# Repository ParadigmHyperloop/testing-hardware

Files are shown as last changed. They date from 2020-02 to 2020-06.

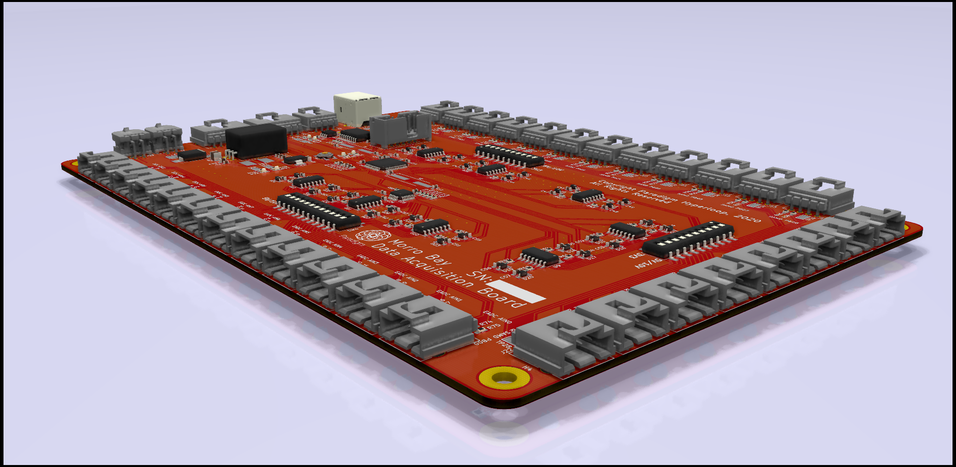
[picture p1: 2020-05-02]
morro-bay/PCB_Morro_Bay/Render1.png

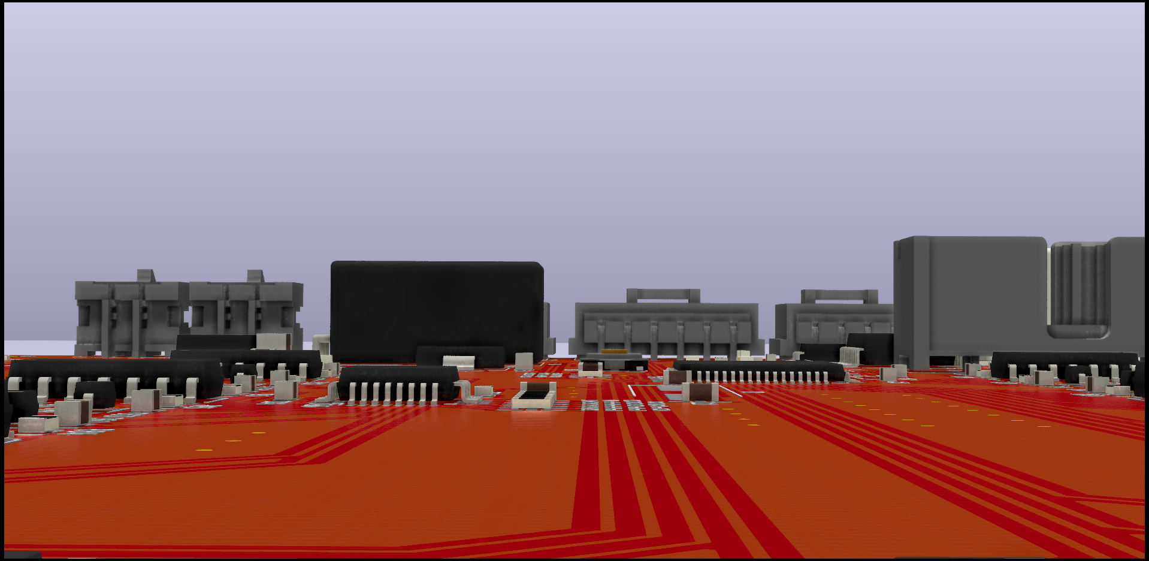
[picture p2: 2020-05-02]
morro-bay/PCB_Morro_Bay/Render4.png

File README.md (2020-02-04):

All schematics and layouts in KiCad, plus some simulations https://paradigmhyperloop.com

License See the LICENSE for full licensing details.

In summary, (you still need to read the whole thing), these boards are for Paradigm, and Paradigm only. It is shared with the world for the benefit of observers and potential Paradigm team members. If you wish to utilize these designs in any way, you must contact us first and receive written permission to utilize the designs for the purpose you require.

We don't want to be restrictive, and we will almost certainly grant you permission, but we want to know what you are using our designs for, and we want to make sure you are using them correctly and safely.

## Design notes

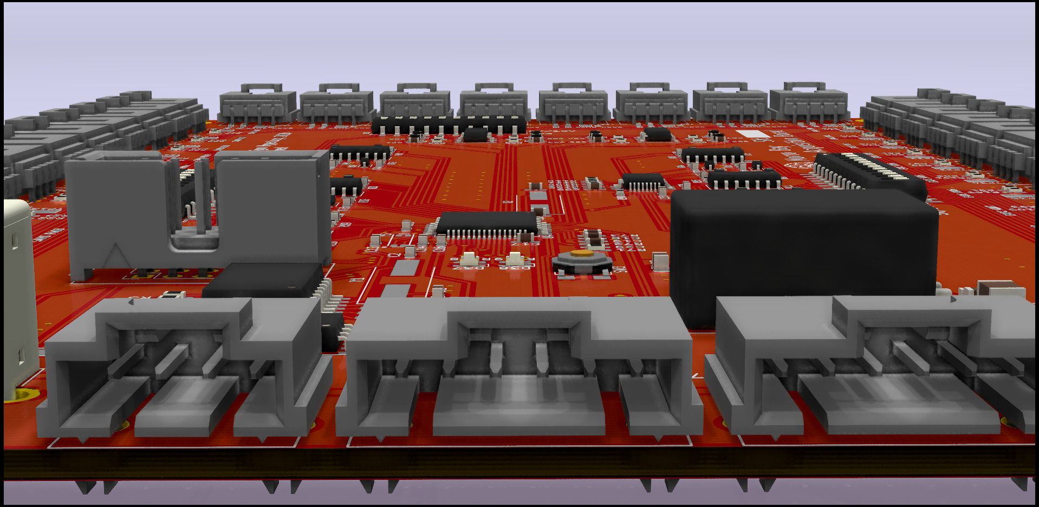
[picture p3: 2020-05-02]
morro-bay/PCB_Morro_Bay/Render2.png

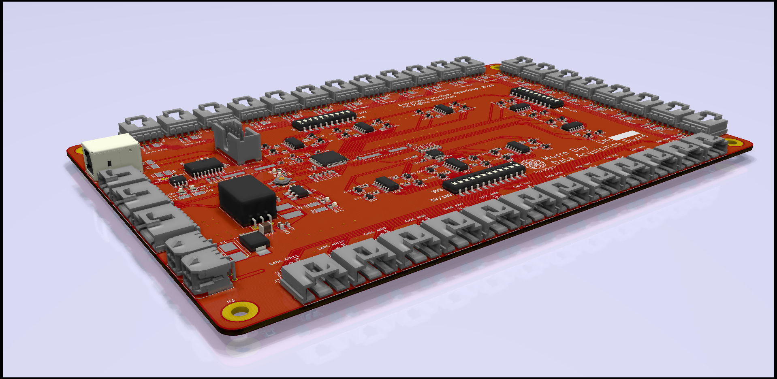
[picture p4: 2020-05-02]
morro-bay/PCB_Morro_Bay/Render3.png

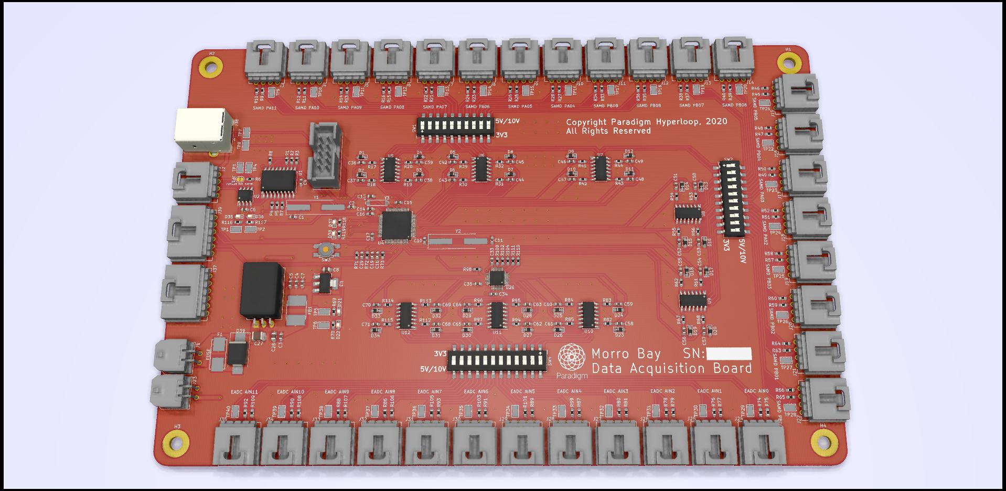
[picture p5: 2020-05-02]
morro-bay/PCB_Morro_Bay/Render5.png

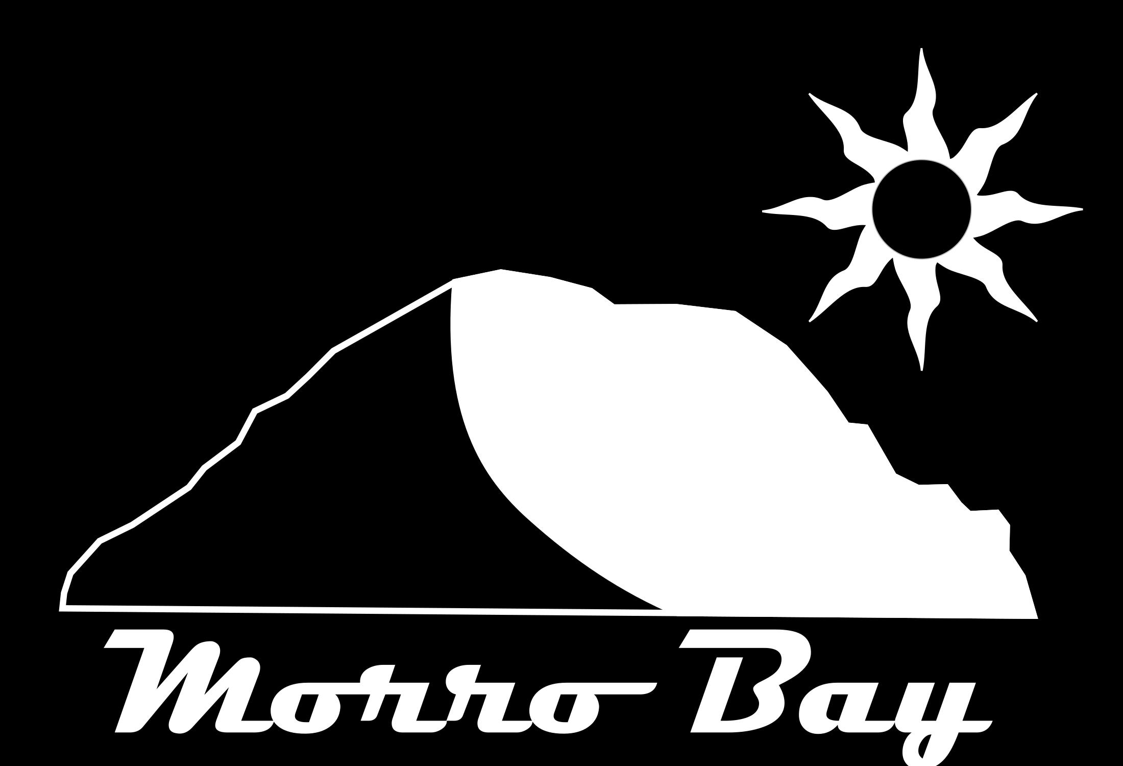
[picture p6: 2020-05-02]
morro-bay/PCB_Morro_Bay/MorroBay.png

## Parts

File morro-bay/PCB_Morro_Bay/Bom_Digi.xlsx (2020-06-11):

Manufacturer Part Number | Manufacturer | Digi-Key Part Number | Reference Designator | Quantity | Unit Price | Extended Price
CL10A106MA8NRNC | Samsung Electro-Mechanics | 1276-1869-1-ND | C5, C7, C12, C21 | 4 | $0.54 | $2.16
CC0603KRX7R8BB104 | Yageo | 311-1341-1-ND | C3, C4, C6, C9, C15-C18, C20, C22-C26, C29-C31, C34-C39, C42-C65, C67-C71 | 52 | $0.08 | $4.16
CL10C180FB8NNNC | Samsung Electro-Mechanics | 1276-2206-1-ND | C1, C2, C10, C11 | 4 | $0.30 | $1.20
CL10C090CB8NNNC | Samsung Electro-Mechanics | 1276-2142-1-ND | C13, C14 | 2 | $0.15 | $0.30
CL10B105KA8NNNC | Samsung Electro-Mechanics | 1276-1184-1-ND | C19 | 1 | $0.15 | $0.15
GRM32EC72A106KE05L | Murata Electronics | 490-16266-1-ND | C27 | 1 | $2.28 | $2.28
CL21A226MAQNNNE | Samsung Electro-Mechanics | 1276-2908-1-ND | C8, C28, C32, C40, C41, C66 | 6 | $0.80 | $4.80
C0603C331J5GACTU | KEMET | 399-1068-1-ND | C33 | 1 | $0.15 | $0.15
MM3Z3V3ST1G | ON Semiconductor | MM3Z3V3ST1GOSCT-ND | D1-D20, D23-D34 | 32 | $0.18 | $5.84
150060VS75000 | Würth Elektronik | 732-4980-1-ND | D21, D22 | 2 | $0.21 | $0.42
LTST-C191KFKT | Lite-On Inc. | 160-1445-1-ND | D35, D36 | 2 | $0.36 | $0.72
150060SS75000 | Würth Elektronik | 732-4979-1-ND | D37 | 1 | $0.21 | $0.21
150060YS75000 | Würth Elektronik | 732-4981-1-ND | D38 | 1 | $0.21 | $0.21
STPS5L60S | STMicroelectronics | 497-8487-1-ND | D39 | 1 | $1.22 | $1.22
0154003.DR | Littelfuse Inc. | F1226CT-ND | F1 | 1 | $3.85 | $3.85
HI2220P701R-10 | Laird-Signal Integrity Products | 240-2428-1-ND | FB1 | 1 | $1.27 | $1.27
FBMH3216HM221NTV | Taiyo Yuden | 587-3834-1-ND | FB2 | 1 | $0.63 | $0.63
0705510038 | Molex | WM14059-ND | J2-J22, J24-J35 | 33 | $2.40 | $79.33
0430450400 | Molex | WM1814-ND | J1, J23 | 2 | $2.01 | $4.02
5103308-1 | TE Connectivity AMP Connectors | A33159-ND | J36 | 1 | $1.98 | $1.98
0705510005 | Molex | WM14056-ND | J37, J39 | 2 | $2.13 | $4.26
UJ2-BH-1-TH | CUI Devices | 102-3999-ND | J38 | 1 | $0.81 | $0.81
RMCF0603FT10K0 | Stackpole Electronics Inc | RMCF0603FT10K0CT-ND | R1-R5, R7, R8, R72 | 8 | $0.16 | $1.28
RMCF0603JT120R | Stackpole Electronics Inc | RMCF0603JT120RCT-ND | R6 | 1 | $0.16 | $0.16
ERJ-PB3B5112V | Panasonic Electronic Components | P20167CT-ND | R9, R11, R13, R15, R21, R23, R25, R27, R33, R35, R37, R39, R45, R47, R74, R76, R78, R80, R99, R101, R103, R105 | 22 | $0.34 | $7.45
ERJ-PB3B1003V | Panasonic Electronic Components | P20200CT-ND | R10, R12, R14, R16, R22, R24, R26, R28, R34, R36, R38, R40, R46, R48, R50, R52, R58, R60, R64, R66, R75, R77, R79, R81, R87, R89, R91, R93, R106-R109 | 32 | $0.25 | $7.88
ERA-3AEB2053V | Panasonic Electronic Components | P205KDBCT-ND | R49, R51, R57, R59, R63, R65, R86, R88, R90, R92 | 10 | $0.46 | $4.60
RMCF0603FT620R | Stackpole Electronics Inc | RMCF0603FT620RCT-ND | R69 | 1 | $0.16 | $0.16
ESR03EZPJ331 | Rohm Semiconductor | RHM330DCT-ND | R70, R71, R118, R119 | 4 | $0.16 | $0.64
RMCF0603JJ1K00 | Stackpole Electronics Inc | RMCF0603JJ1K00CT-ND | R73 | 1 | $0.16 | $0.16
RMCF0603FT47R0 | Stackpole Electronics Inc | RMCF0603FT47R0CT-ND | R98, R100, R102, R104, R110, R111 | 6 | $0.16 | $0.96
RMCF0603FT470R | Stackpole Electronics Inc | RMCF0603FT470RCT-ND | R17-R20, R29-R32, R41-R44, R53-R56, R61, R62, R67, R68, R82-R85, R94-R97, R112-R117 | 34 | $0.03 | $0.88
DS04-254-2-10BK-SMT | CUI Devices | 2223-DS04-254-2-10BK-SMT-ND | SW1, SW2 | 2 | $1.72 | $3.44
TL3305AF160QG | E-Switch | EG5350CT-ND | SW3 | 1 | $0.32 | $0.32
DS04-254-2-12BK-SMT | CUI Devices | 2223-DS04-254-2-12BK-SMT-ND | SW4 | 1 | $1.83 | $1.83
5015 | Keystone Electronics | 36-5015CT-ND | TP1-TP40 | 40 | $0.58 | $23.05
MCP2515T-I/SO | Microchip Technology | MCP2515T-I/SOCT-ND | U1 | 1 | $2.92 | $2.92
SN65HVD232DR | Texas Instruments | 296-26344-1-ND | U2 | 1 | $3.13 | $3.13
AZ1117IH-3.3TRG1 | Diodes Incorporated | AZ1117IH-3.3TRG1DICT-ND | U3 | 1 | $0.58 | $0.58
ATSAMD21J18A-AUT | Microchip Technology | ATSAMD21J18A-AUTCT-ND | U4 | 1 | $5.29 | $5.29
LM2902LVIDR | Texas Instruments | 296-51255-1-ND | U5-U12 | 8 | $0.77 | $6.16
V7805-2000R | CUI Inc. | 102-2188-ND | U13 | 1 | $14.71 | $14.71
ADS114S08BIPBSR | Texas Instruments | 296-50714-1-ND | U26 | 1 | $13.29 | $13.29
ABLS2-8.000MHZ-D4Y-T | Abracon LLC | 535-9864-1-ND | Y1 | 1 | $0.74 | $0.74
ABLS2-30.000MHZ-D4YF-T | Abracon LLC | 535-9887-1-ND | Y2 | 1 | $0.69 | $0.69
MC-146 32.7680KA-AC0: ROHS | EPSON | SER4303CT-ND | Y3 | 1 | $0.64 | $0.64
 |  |  |  |  |  | $220.93

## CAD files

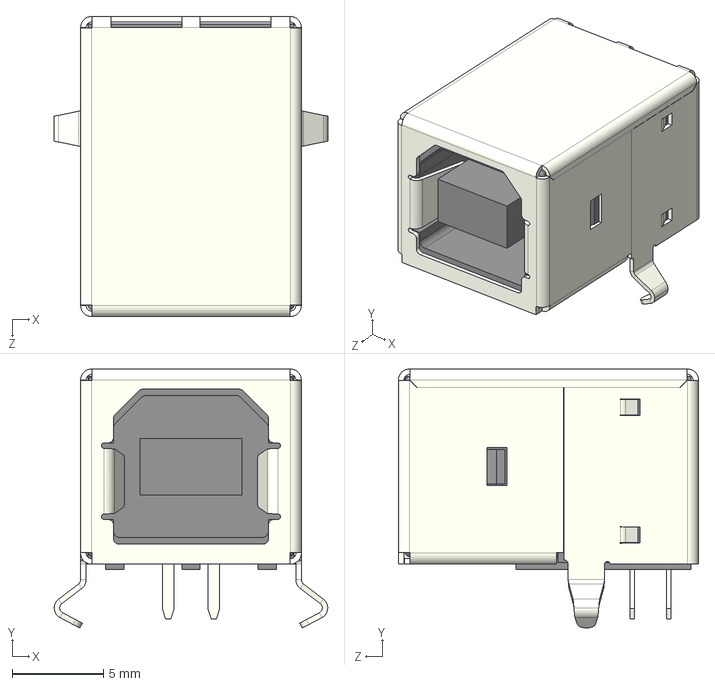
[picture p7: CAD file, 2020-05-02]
morro-bay/Models/CUI_DEVICES_UJ2-BH-1-TH.step
15.0 x 14.2 x 16.5 mm

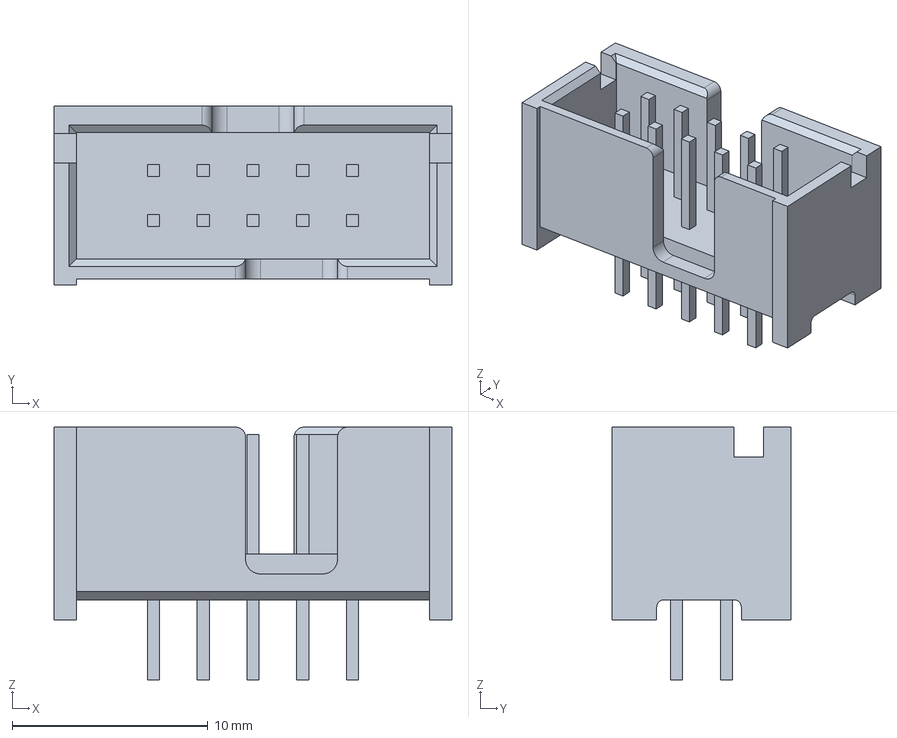
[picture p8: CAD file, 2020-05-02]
morro-bay/Models/c-5103308-1-b-3d.stp
20.3 x 9.14 x 12.9 mm

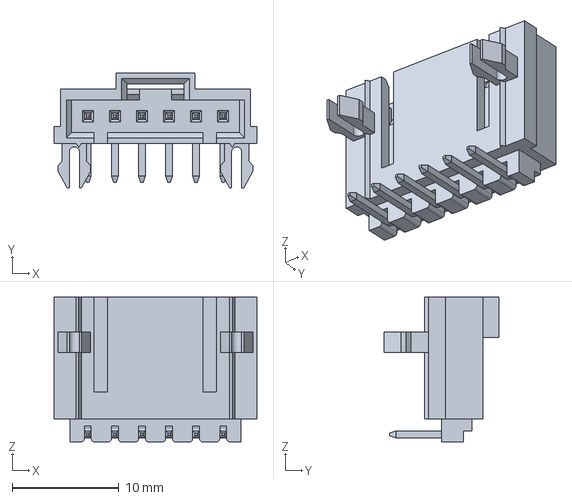
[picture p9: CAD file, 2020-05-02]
morro-bay/Models/705510005.stp
19.0 x 10.8 x 13.6 mm

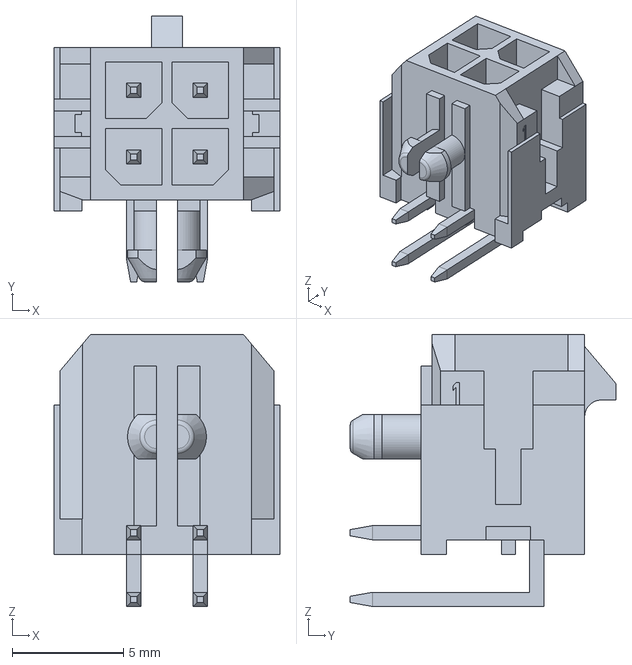
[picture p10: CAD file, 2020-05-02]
morro-bay/Models/430450400.stp
10.2 x 11.9 x 12.2 mm

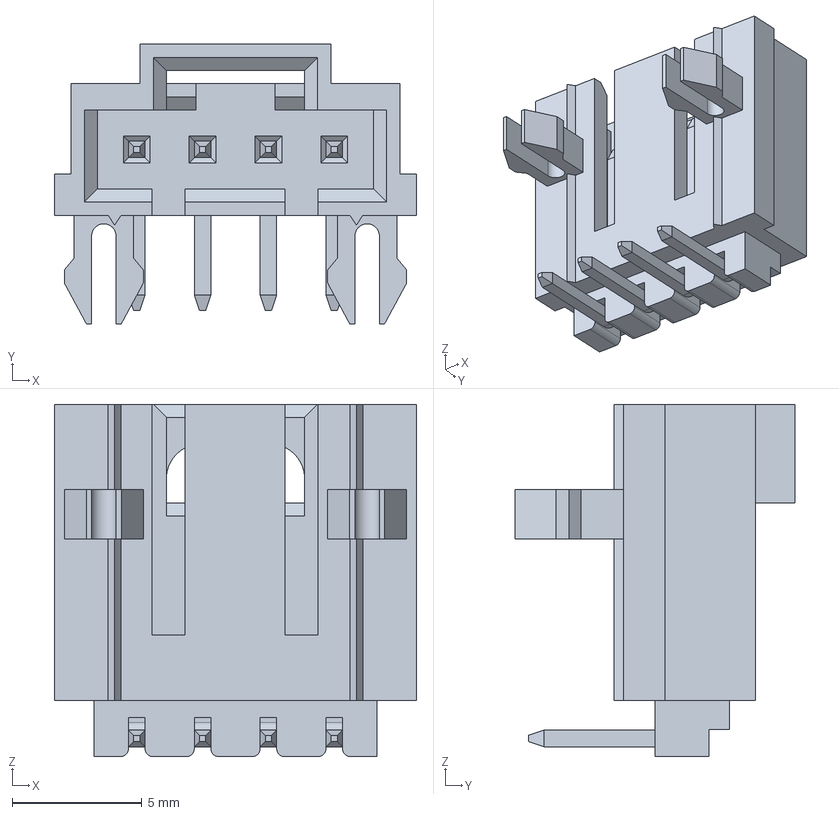
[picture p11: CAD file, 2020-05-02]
morro-bay/Models/705510038.stp
14.0 x 10.8 x 13.6 mm

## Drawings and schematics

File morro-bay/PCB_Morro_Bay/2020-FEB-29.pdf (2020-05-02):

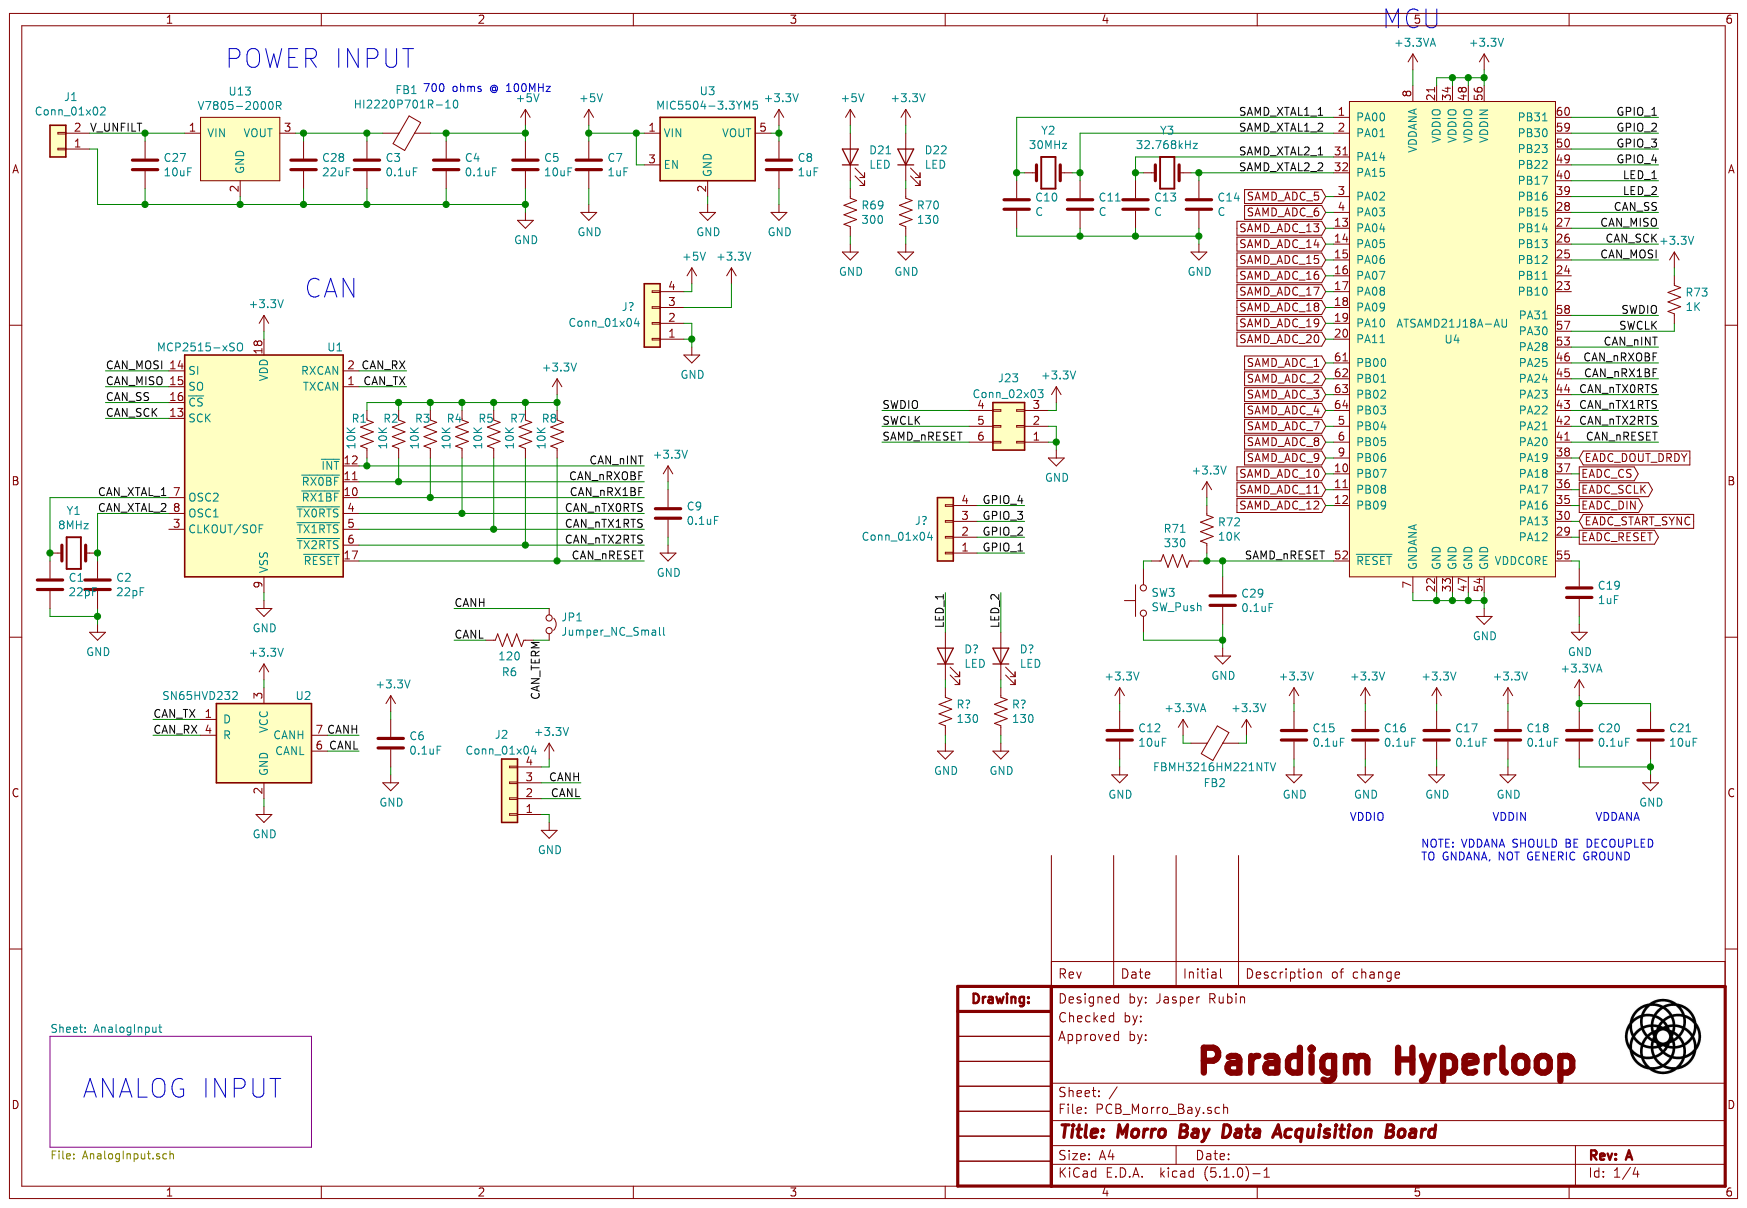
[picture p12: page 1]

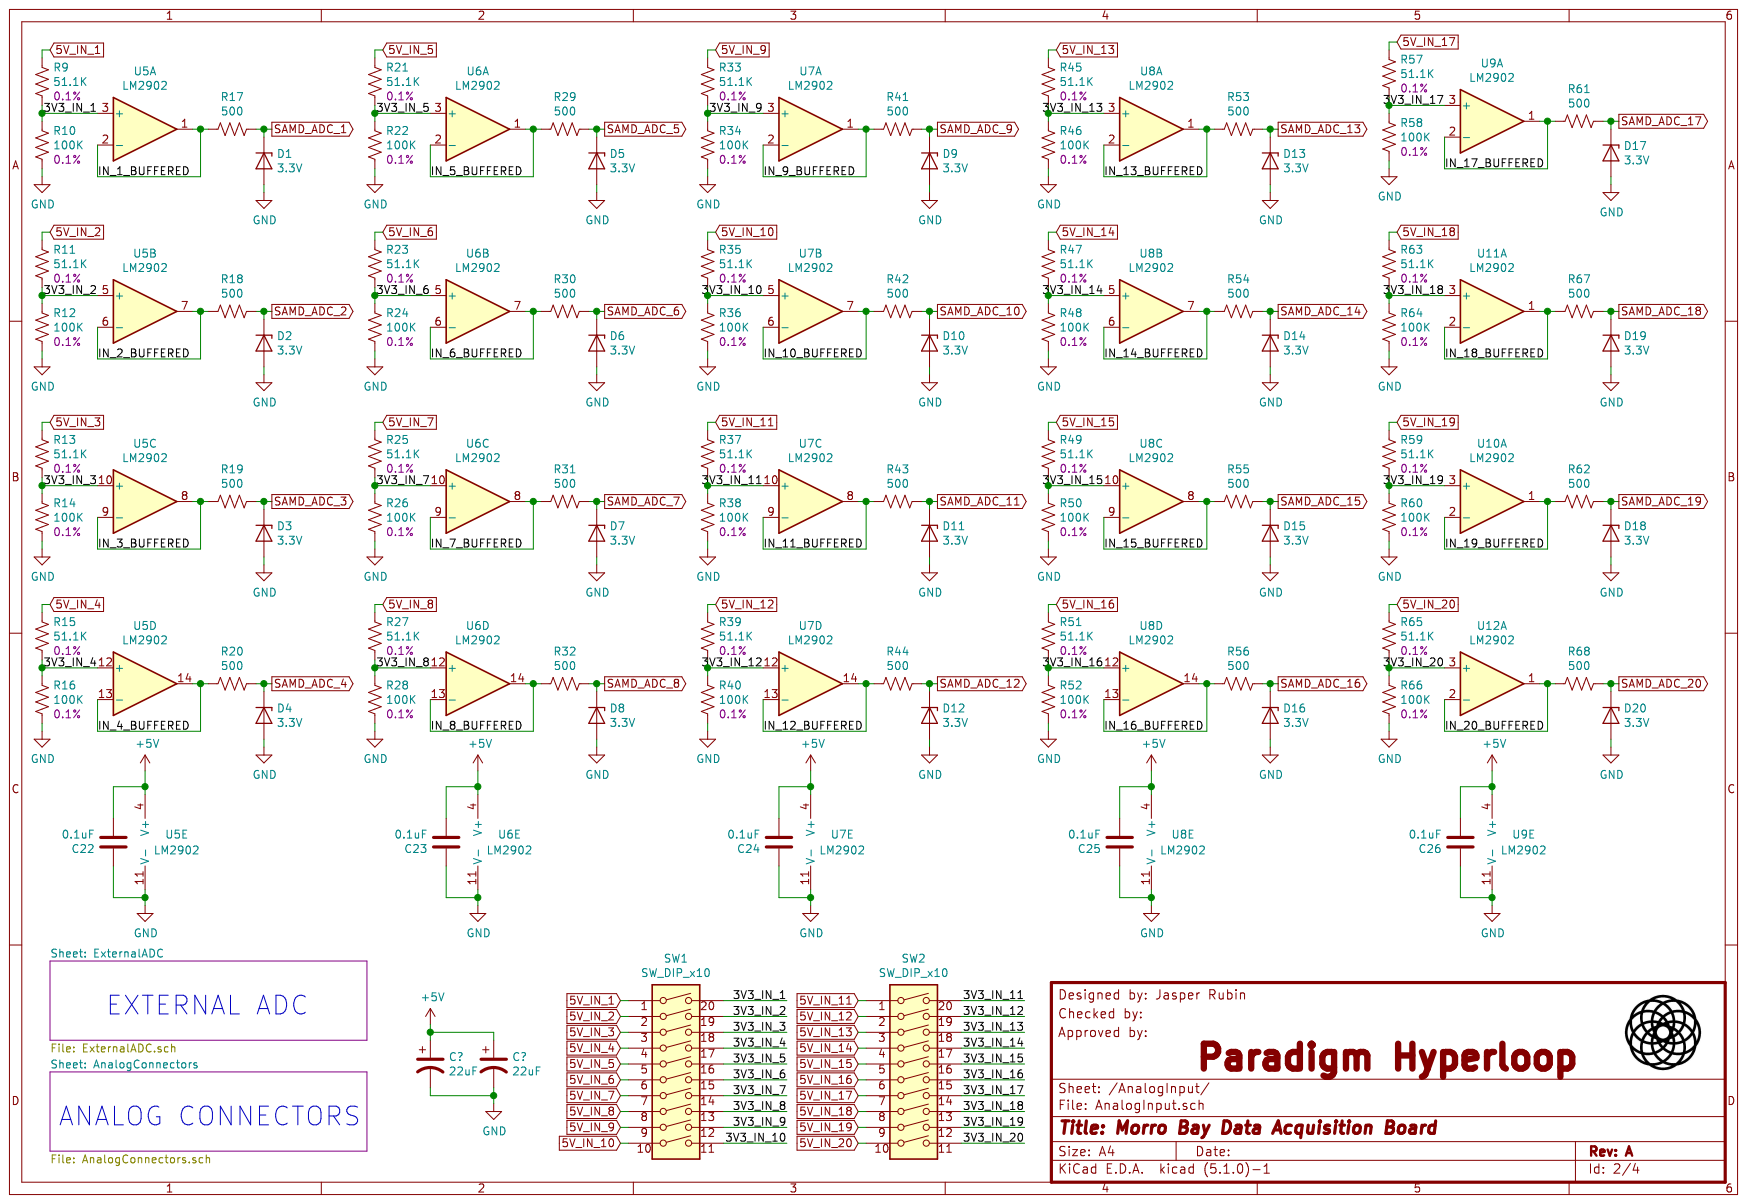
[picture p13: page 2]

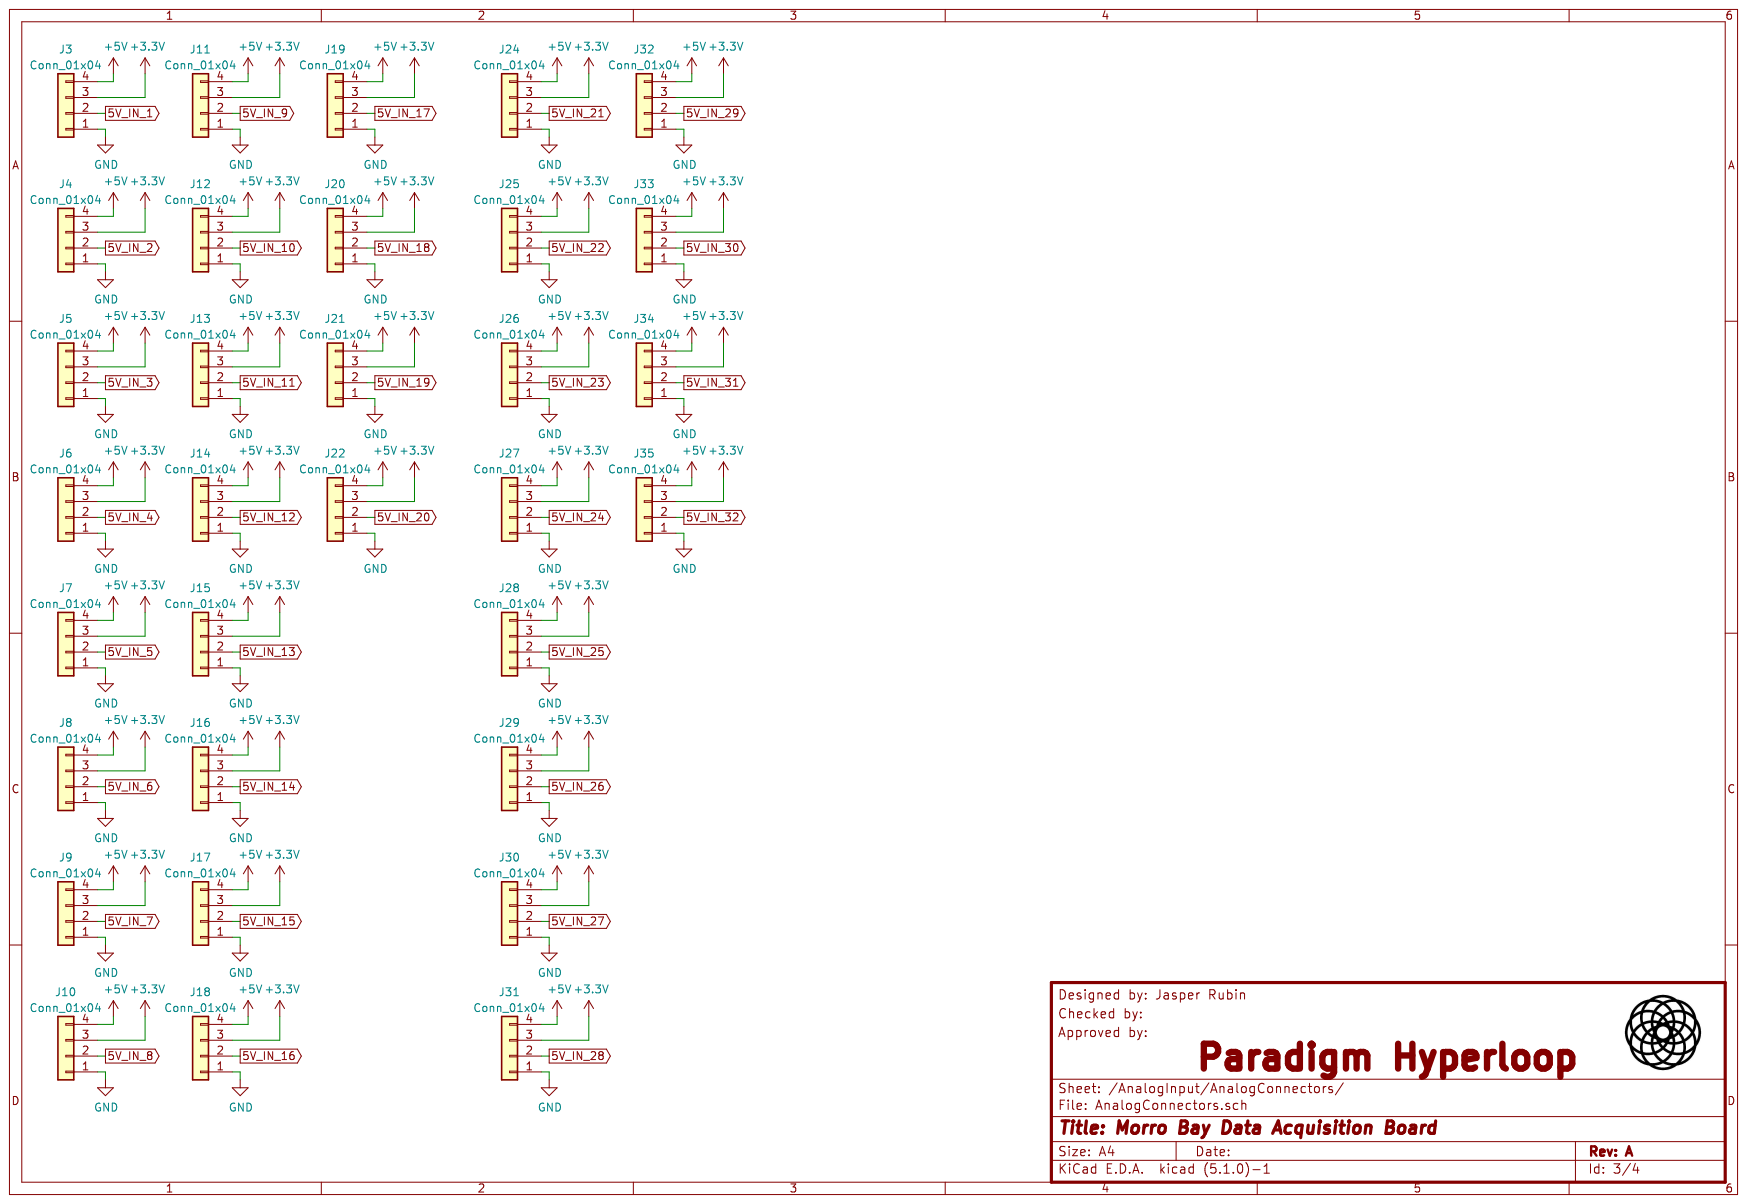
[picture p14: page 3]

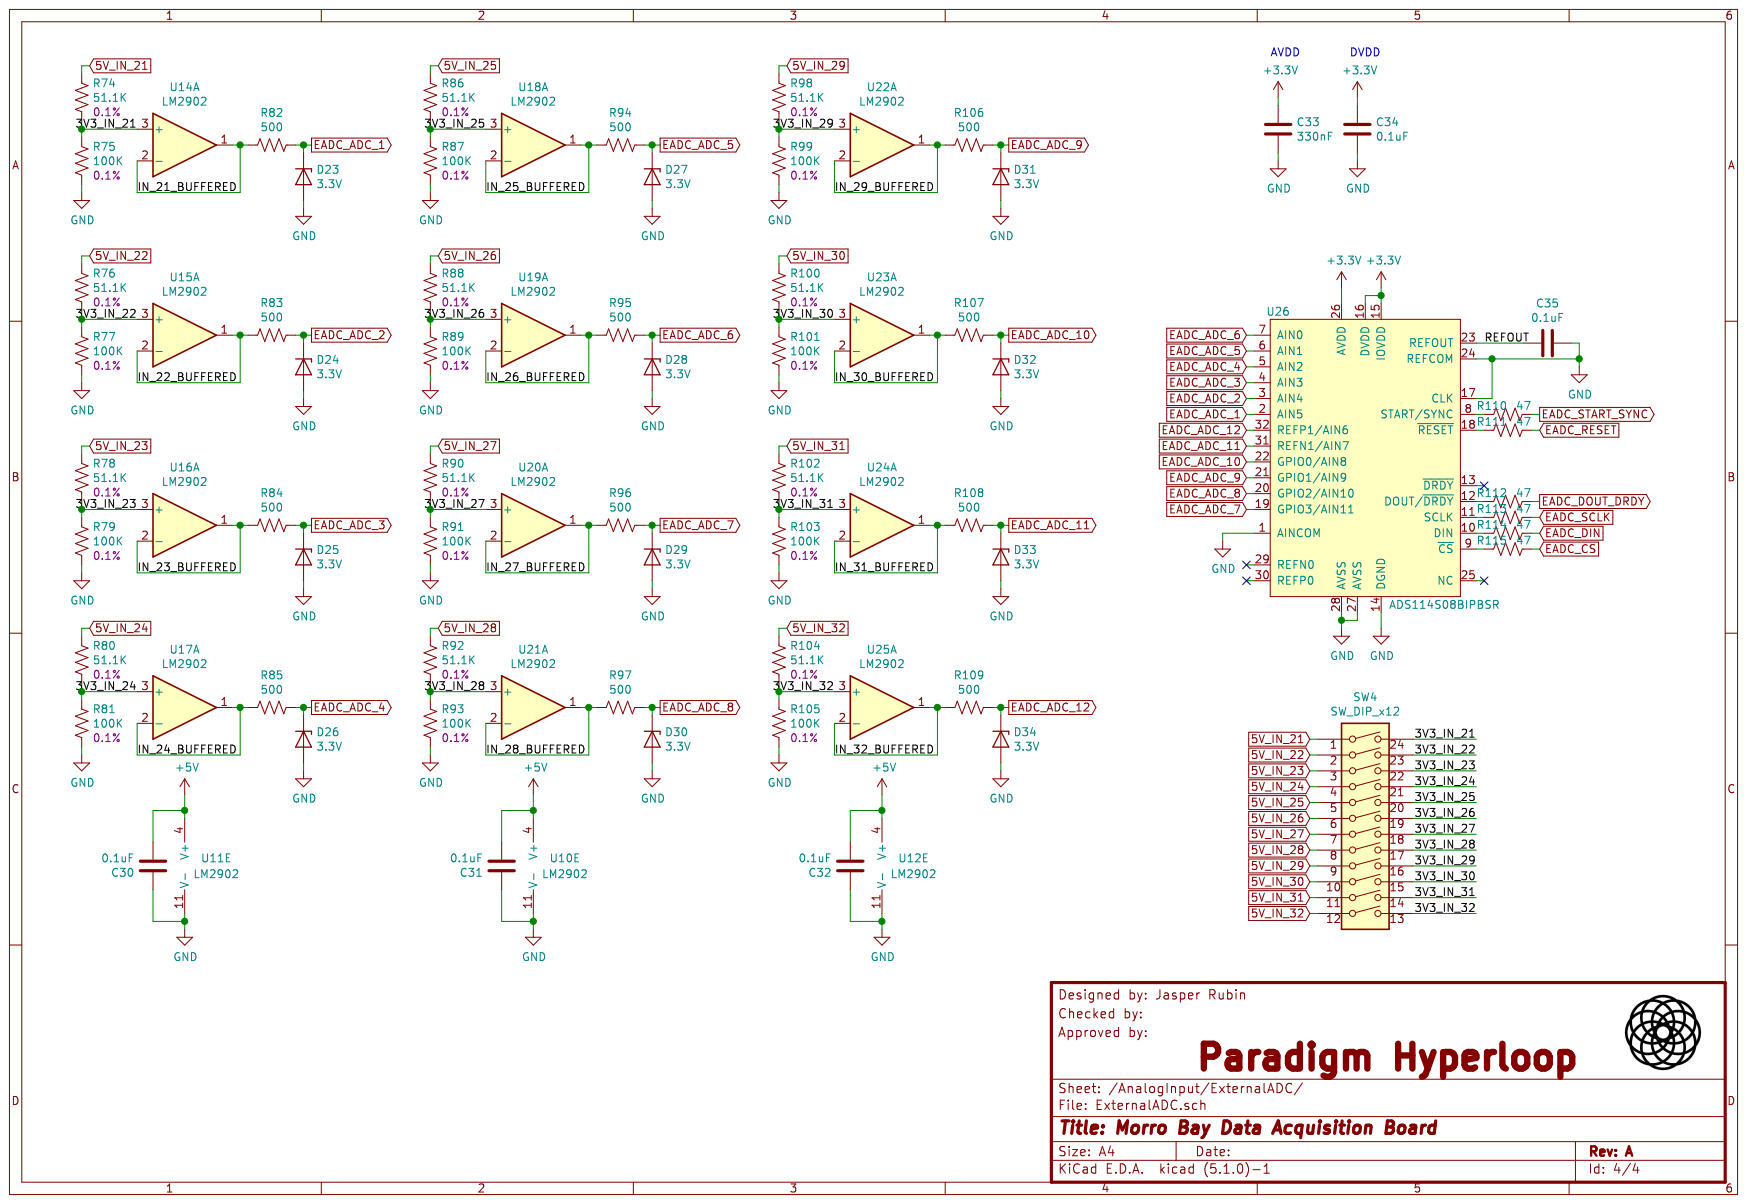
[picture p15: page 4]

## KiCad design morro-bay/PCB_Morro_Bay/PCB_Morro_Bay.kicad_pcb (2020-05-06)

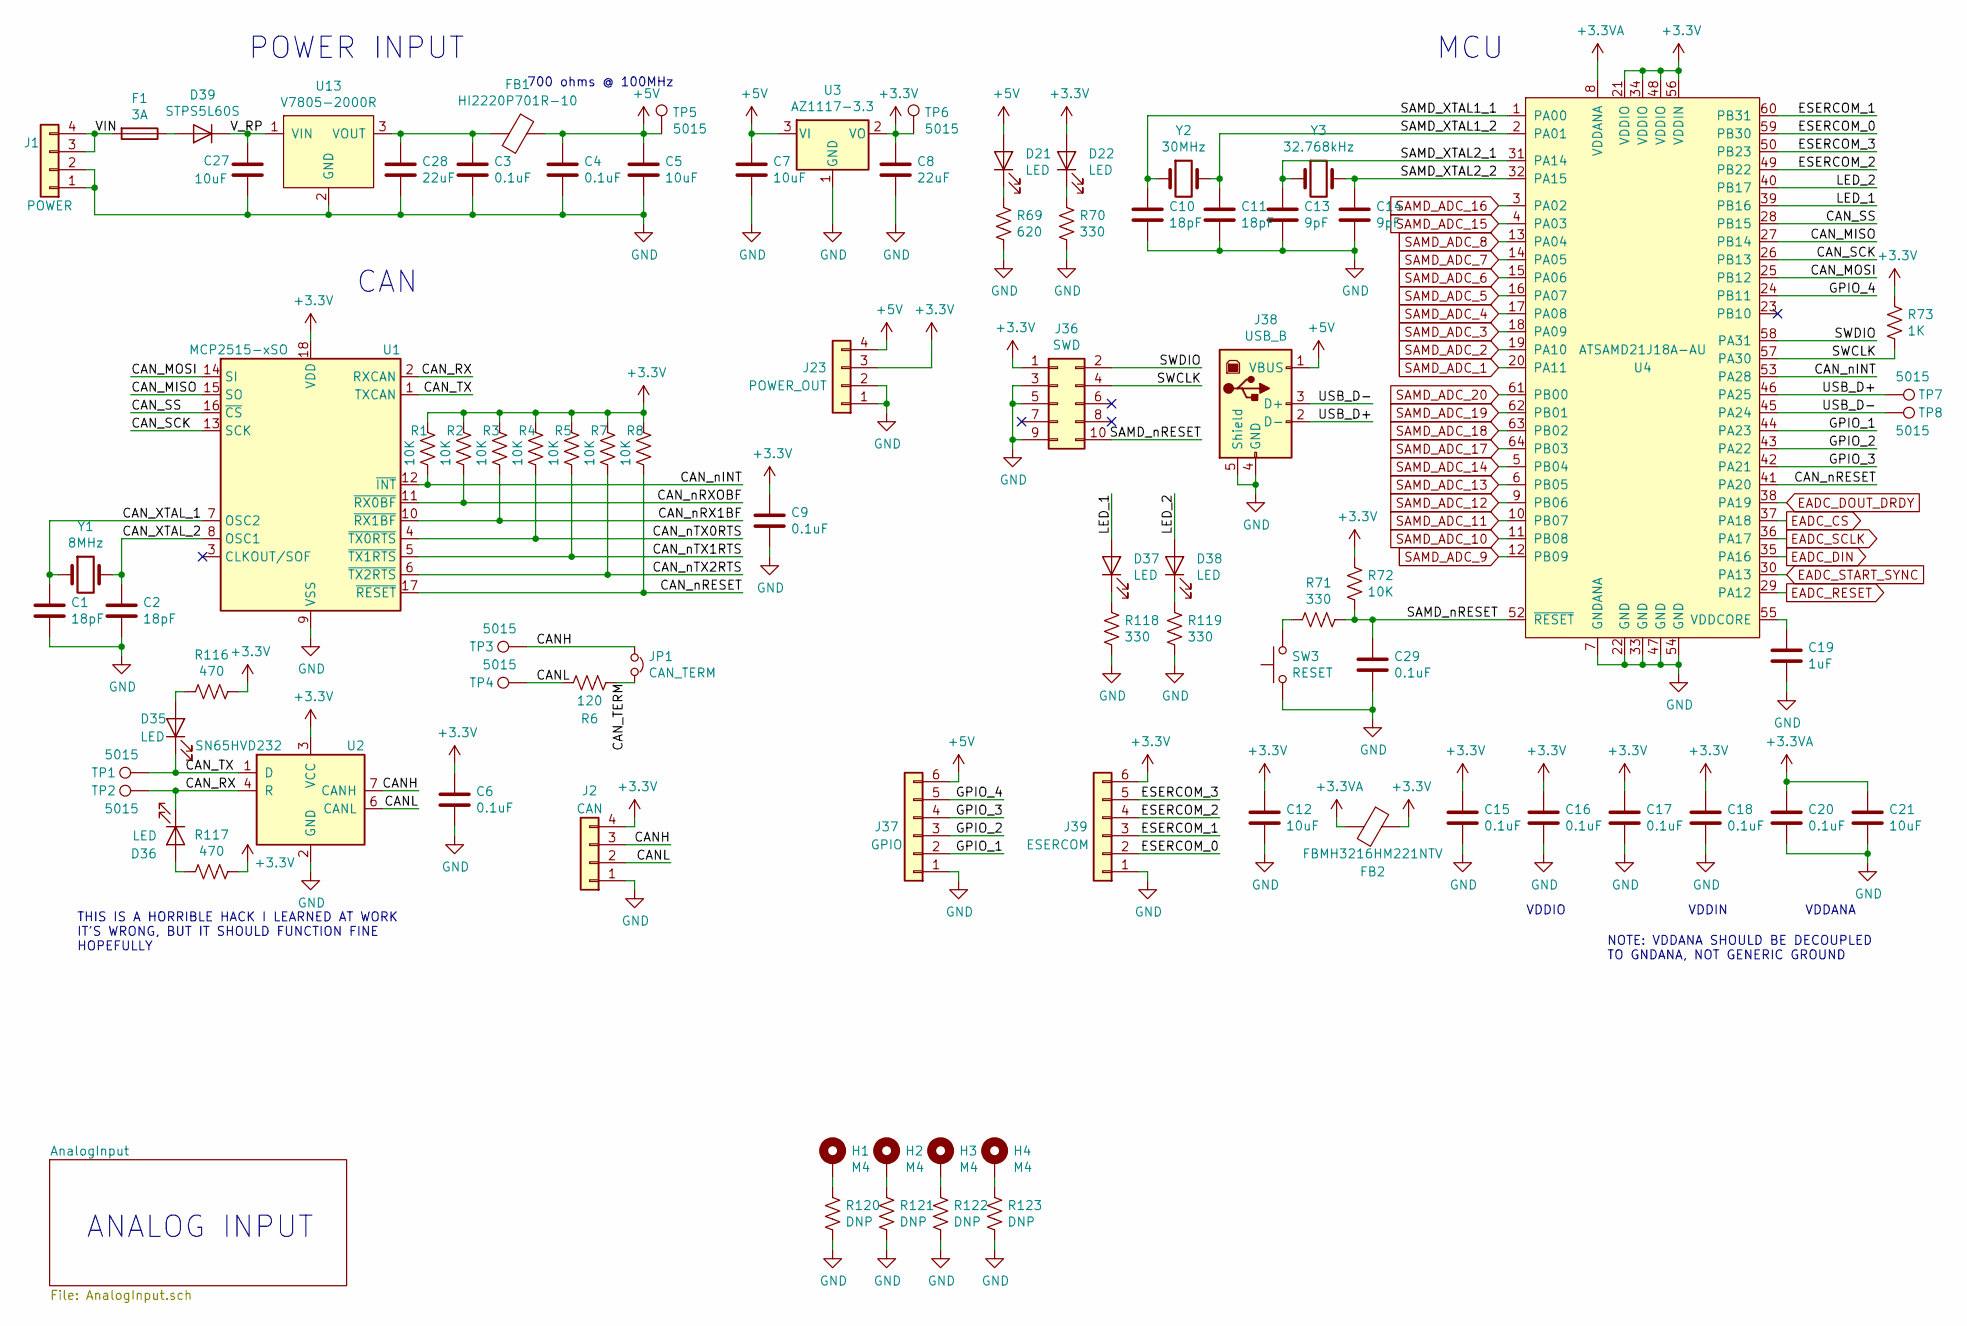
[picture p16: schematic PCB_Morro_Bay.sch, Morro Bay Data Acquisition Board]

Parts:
C1, C2, C10, C11: 18pF; C_0603_1608Metric_Pad1.05x0.95mm_HandSolder; Part Number CL10C180FB8NNNC
C3, C4, C6, C9, C15, C16, C17, C18, C20, C29: 0.1uF; C_0603_1608Metric_Pad1.05x0.95mm_HandSolder; Part Number CC0603KRX7R8BB104
C5, C7, C12, C21: 10uF; C_0603_1608Metric_Pad1.05x0.95mm_HandSolder; Part Number CL10A106MA8NRNC
C8, C28: 22uF; C_0805_2012Metric_Pad1.15x1.40mm_HandSolder; Part Number CL21A226MAQNNNE
C13, C14: 9pF; C_0603_1608Metric_Pad1.05x0.95mm_HandSolder; Part Number CL10C090CB8NNNC
C19: 1uF; C_0603_1608Metric_Pad1.05x0.95mm_HandSolder; Part Number CL10B105KA8NNNC
C27: 10uF; C_1210_3225Metric_Pad1.42x2.65mm_HandSolder; Part Number GRM32EC72A106KE05L
D21, D22: LED; LED_0603_1608Metric_Castellated; Part Number 150060VS75000
D35, D36: LED; LED_0603_1608Metric_Castellated; Part Number LTST-C191KFKT
D37: LED; LED_0603_1608Metric_Castellated; Part Number 150060SS75000
D38: LED; LED_0603_1608Metric_Castellated; Part Number 150060YS75000
D39: STPS5L60S; D_SMC_Handsoldering; Part Number STPS5L60S
F1: 3A; Fuse_Littelfuse_0154003.DR; Part Number 0154003.DR
FB1: HI2220P701R-10; Ferrite_Laird_HI2220P701R-10; Part Number HI2220P701R-10
FB2: FBMH3216HM221NTV; L_1206_3216Metric_Pad1.42x1.75mm_HandSolder; Part Number FBMH3216HM221NTV
H1, H2, H3, H4: M4; MountingHole_4.3mm_M4_Pad
J1: POWER; Molex_Micro-Fit_3.0_43045-0400_2x02_P3.00mm_Horizontal; Part Number 0430450400
J2: CAN; Connector_Molex_SL_4POS_0705510038; Part Number 0705510038
J23: POWER_OUT; Molex_Micro-Fit_3.0_43045-0400_2x02_P3.00mm_Horizontal; Part Number 0430450400
J36: SWD; Connector_TE_5103308-1; Part Number 5103308-1
J37: GPIO; Connector_Molex_SL_6POS_0705510005; Part Number 0705510005
J38: USB_B; USB_B_OST_USB-B1HSxx_Horizontal; Part Number UJ2-BH-1-TH
J39: ESERCOM; Connector_Molex_SL_6POS_0705510005; Part Number 0705510005
JP1: CAN_TERM; SolderJumper-2_P1.3mm_Open_RoundedPad1.0x1.5mm
R1, R2, R3, R4, R5, R7, R8, R72: 10K; R_0603_1608Metric_Pad1.05x0.95mm_HandSolder; Part Number RMCF0603FT10K0
R6: 120; R_0603_1608Metric_Pad1.05x0.95mm_HandSolder; Part Number RMCF0603JT120R
R69: 620; R_0603_1608Metric_Pad1.05x0.95mm_HandSolder; Part Number RMCF0603FT620R
R70, R71, R118, R119: 330; R_0603_1608Metric_Pad1.05x0.95mm_HandSolder; Part Number ESR03EZPJ331
R73: 1K; R_0603_1608Metric_Pad1.05x0.95mm_HandSolder; Part Number RMCF0603JJ1K00
R116, R117: 470; R_0603_1608Metric_Pad1.05x0.95mm_HandSolder; Part Number RMCF0603FT470R
R120, R121, R122, R123: DNP; R_0805_2012Metric_Pad1.15x1.40mm_HandSolder
SW3: RESET; SW_SPST_TL3305A; Part Number TL3305AF160QG
TP1, TP2, TP3, TP4, TP5, TP6, TP7, TP8: 5015; TestPoint_Keystone_5015_Micro-Minature; Part Number 5015
U1: MCP2515-xSO; SOIC-18W_7.5x11.6mm_P1.27mm; Part Number MCP2515T-I/SO
U2: SN65HVD232; SOIC-8_3.9x4.9mm_P1.27mm; Part Number SN65HVD232DR
U3: AZ1117-3.3; SOT-223-3_TabPin2; Part Number AZ1117IH-3.3TRG1
U4: ATSAMD21J18A-AU; TQFP-64_10x10mm_P0.5mm; Part Number ATSAMD21J18A-AUT
U13: V7805-2000R; Converter_DCDC_RECOM_R-78HB-0.5L_THT; Part Number V7805-2000R
Y1: 8MHz; Crystal_SMD_HC49-SD_HandSoldering; Part Number ABLS2-8.000MHZ-D4Y-T
Y2: 30MHz; Crystal_SMD_HC49-SD_HandSoldering; Part Number ABLS2-30.000MHZ-D4YF-T
Y3: 32.768kHz; Crystal_Epson_MC-146; Part Number MC-146 32.7680KA-AC0: ROHS

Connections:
+3.3VA: C20.1, C21.1, FB2.2, U4.8 (VDDANA)
+3V3: C6.1, C8.1, C9.1, C12.1, C15.1, C16.1, C17.1, C18.1, D22.2 (A), FB2.1, J2.4, J23.3, J36.1, J39.6, R1.1, R2.1, R3.1, R4.1, R5.1, R7.1, R8.1, R72.1, R73.1, R116.1, R117.1, TP6.1, U1.18 (VDD), U2.3 (VCC), U3.2 (VO), U4.21 (VDDIO), U4.34 (VDDIO), U4.48 (VDDIO), U4.56 (VDDIN); also elsewhere on the board
+5V: C4.1, C5.1, C7.1, D21.2 (A), FB1.1, J23.4, J37.6, J38.1 (VBUS), TP5.1, U3.3 (VI); also elsewhere on the board
/CANH: J2.3, JP1.1, TP3.1, U2.7 (CANH)
/CANL: J2.2, R6.2, TP4.1, U2.6 (CANL)
/CAN_MISO: U1.15 (SO), U4.27 (PB14)
/CAN_MOSI: U1.14 (SI), U4.25 (PB12)
/CAN_RX: D36.1 (K), TP2.1, U1.2 (RXCAN), U2.4 (R)
/CAN_SCK: U1.13 (SCK), U4.26 (PB13)
/CAN_SS: U1.16 (~CS), U4.28 (PB15)
/CAN_TERM: JP1.2, R6.1
/CAN_TX: D35.1 (K), TP1.1, U1.1 (TXCAN), U2.1 (D)
/CAN_XTAL_1: C1.1, U1.7 (OSC2), Y1.1
/CAN_XTAL_2: C2.1, U1.8 (OSC1), Y1.2
/CAN_nINT: R1.2, U1.12 (~INT), U4.53 (PA28)
/CAN_nRESET: R8.2, U1.17 (~RESET), U4.41 (PA20)
/CAN_nRX1BF: R3.2, U1.10 (~RX1BF)
/CAN_nRXOBF: R2.2, U1.11 (~RX0BF)
/CAN_nTX0RTS: R4.2, U1.4 (~TX0RTS)
/CAN_nTX1RTS: R5.2, U1.5 (~TX1RTS)
/CAN_nTX2RTS: R7.2, U1.6 (~TX2RTS)
/ESERCOM_0: J39.2, U4.59 (PB30)
/ESERCOM_1: J39.3, U4.60 (PB31)
/ESERCOM_2: J39.4, U4.49 (PB22)
/ESERCOM_3: J39.5, U4.50 (PB23)
/GPIO_1: J37.2, U4.44 (PA23)
/GPIO_2: J37.3, U4.43 (PA22)
/GPIO_3: J37.4, U4.42 (PA21)
/GPIO_4: J37.5, U4.24 (PB11)
/LED_1: D37.2 (A), U4.39 (PB16)
/LED_2: D38.2 (A), U4.40 (PB17)
/SAMD_XTAL1_1: C10.1, U4.1 (PA00), Y2.1
/SAMD_XTAL1_2: C11.1, U4.2 (PA01), Y2.2
/SAMD_XTAL2_1: C13.1, U4.31 (PA14), Y3.1
/SAMD_XTAL2_2: C14.1, U4.32 (PA15), Y3.2
/SAMD_nRESET: C29.1, J36.10, R71.1, R72.2, U4.52 (~RESET~)
/SWCLK: J36.4, R73.2, U4.57 (PA30)
/SWDIO: J36.2, U4.58 (PA31)
/USB_D+: J38.2 (D-), TP7.1, U4.46 (PA25)
/USB_D-: J38.3 (D+), TP8.1, U4.45 (PA24)
/VIN: F1.2, J1.3, J1.4
/V_RP: C27.1, D39.1 (K), U13.1 (VIN)
EADC_CS: U4.37 (PA18); also elsewhere on the board
EADC_DIN: U4.35 (PA16); also elsewhere on the board
EADC_DOUT_DRDY: U4.38 (PA19); also elsewhere on the board
EADC_RESET: U4.29 (PA12); also elsewhere on the board
EADC_SCLK: U4.36 (PA17); also elsewhere on the board
EADC_START_SYNC: U4.30 (PA13); also elsewhere on the board
GND: C1.2, C2.2, C3.2, C4.2, C5.2, C6.2, C7.2, C8.2, C9.2, C10.2, C11.2, C12.2, C13.2, C14.2, C15.2, C16.2, C17.2, C18.2, C19.2, C20.2, C21.2, C27.2, C28.2, C29.2, J1.1, J1.2, J2.1, J23.1, J23.2, J36.3, J36.5, J36.9, J37.1, J38.4 (GND), J38.5 (Shield), J39.1, R69.2, R70.2, R118.2, R119.2, R120.2, R121.2, R122.2, R123.2, SW3.1, U1.9 (VSS), U2.2 (GND), U3.1 (GND), U4.7 (GNDANA), U4.22 (GND), U4.33 (GND), U4.47 (GND), U4.54 (GND), U13.2 (GND); also elsewhere on the board
unnamed: C19.1, U4.55 (VDDCORE)
unnamed: C3.1, C28.1, FB1.2, U13.3 (VOUT)
unnamed: D21.1 (K), R69.1
unnamed: D22.1 (K), R70.1
unnamed: D35.2 (A), R116.2
unnamed: D36.2 (A), R117.2
unnamed: D37.1 (K), R118.1
unnamed: D38.1 (K), R119.1
unnamed: D39.2 (A), F1.1
unnamed: H1.1, R120.1
unnamed: H2.1, R121.1
unnamed: H3.1, R122.1
unnamed: H4.1, R123.1
unnamed: R71.2, SW3.2
SAMD_ADC_1: U4.20 (PA11); also elsewhere on the board
SAMD_ADC_2: U4.19 (PA10); also elsewhere on the board
SAMD_ADC_3: U4.18 (PA09); also elsewhere on the board
SAMD_ADC_4: U4.17 (PA08); also elsewhere on the board
SAMD_ADC_5: U4.16 (PA07); also elsewhere on the board
SAMD_ADC_6: U4.15 (PA06); also elsewhere on the board
SAMD_ADC_7: U4.14 (PA05); also elsewhere on the board
SAMD_ADC_8: U4.13 (PA04); also elsewhere on the board
SAMD_ADC_9: U4.12 (PB09); also elsewhere on the board
SAMD_ADC_10: U4.11 (PB08); also elsewhere on the board
SAMD_ADC_11: U4.10 (PB07); also elsewhere on the board
SAMD_ADC_12: U4.9 (PB06); also elsewhere on the board
SAMD_ADC_13: U4.6 (PB05); also elsewhere on the board
SAMD_ADC_14: U4.5 (PB04); also elsewhere on the board
SAMD_ADC_15: U4.4 (PA03); also elsewhere on the board
SAMD_ADC_16: U4.3 (PA02); also elsewhere on the board
SAMD_ADC_17: U4.64 (PB03); also elsewhere on the board
SAMD_ADC_18: U4.63 (PB02); also elsewhere on the board
SAMD_ADC_19: U4.62 (PB01); also elsewhere on the board
SAMD_ADC_20: U4.61 (PB00); also elsewhere on the board

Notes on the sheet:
POWER INPUT
CAN
VDDIO
VDDIN
VDDANA
NOTE: VDDANA SHOULD BE DECOUPLED TO GNDANA, NOT GENERIC GROUND
MCU
ANALOG INPUT
700 ohms @ 100MHz
THIS IS A HORRIBLE HACK I LEARNED AT WORK IT'S WRONG, BUT IT SHOULD FUNCTION FINE HOPEFULLY

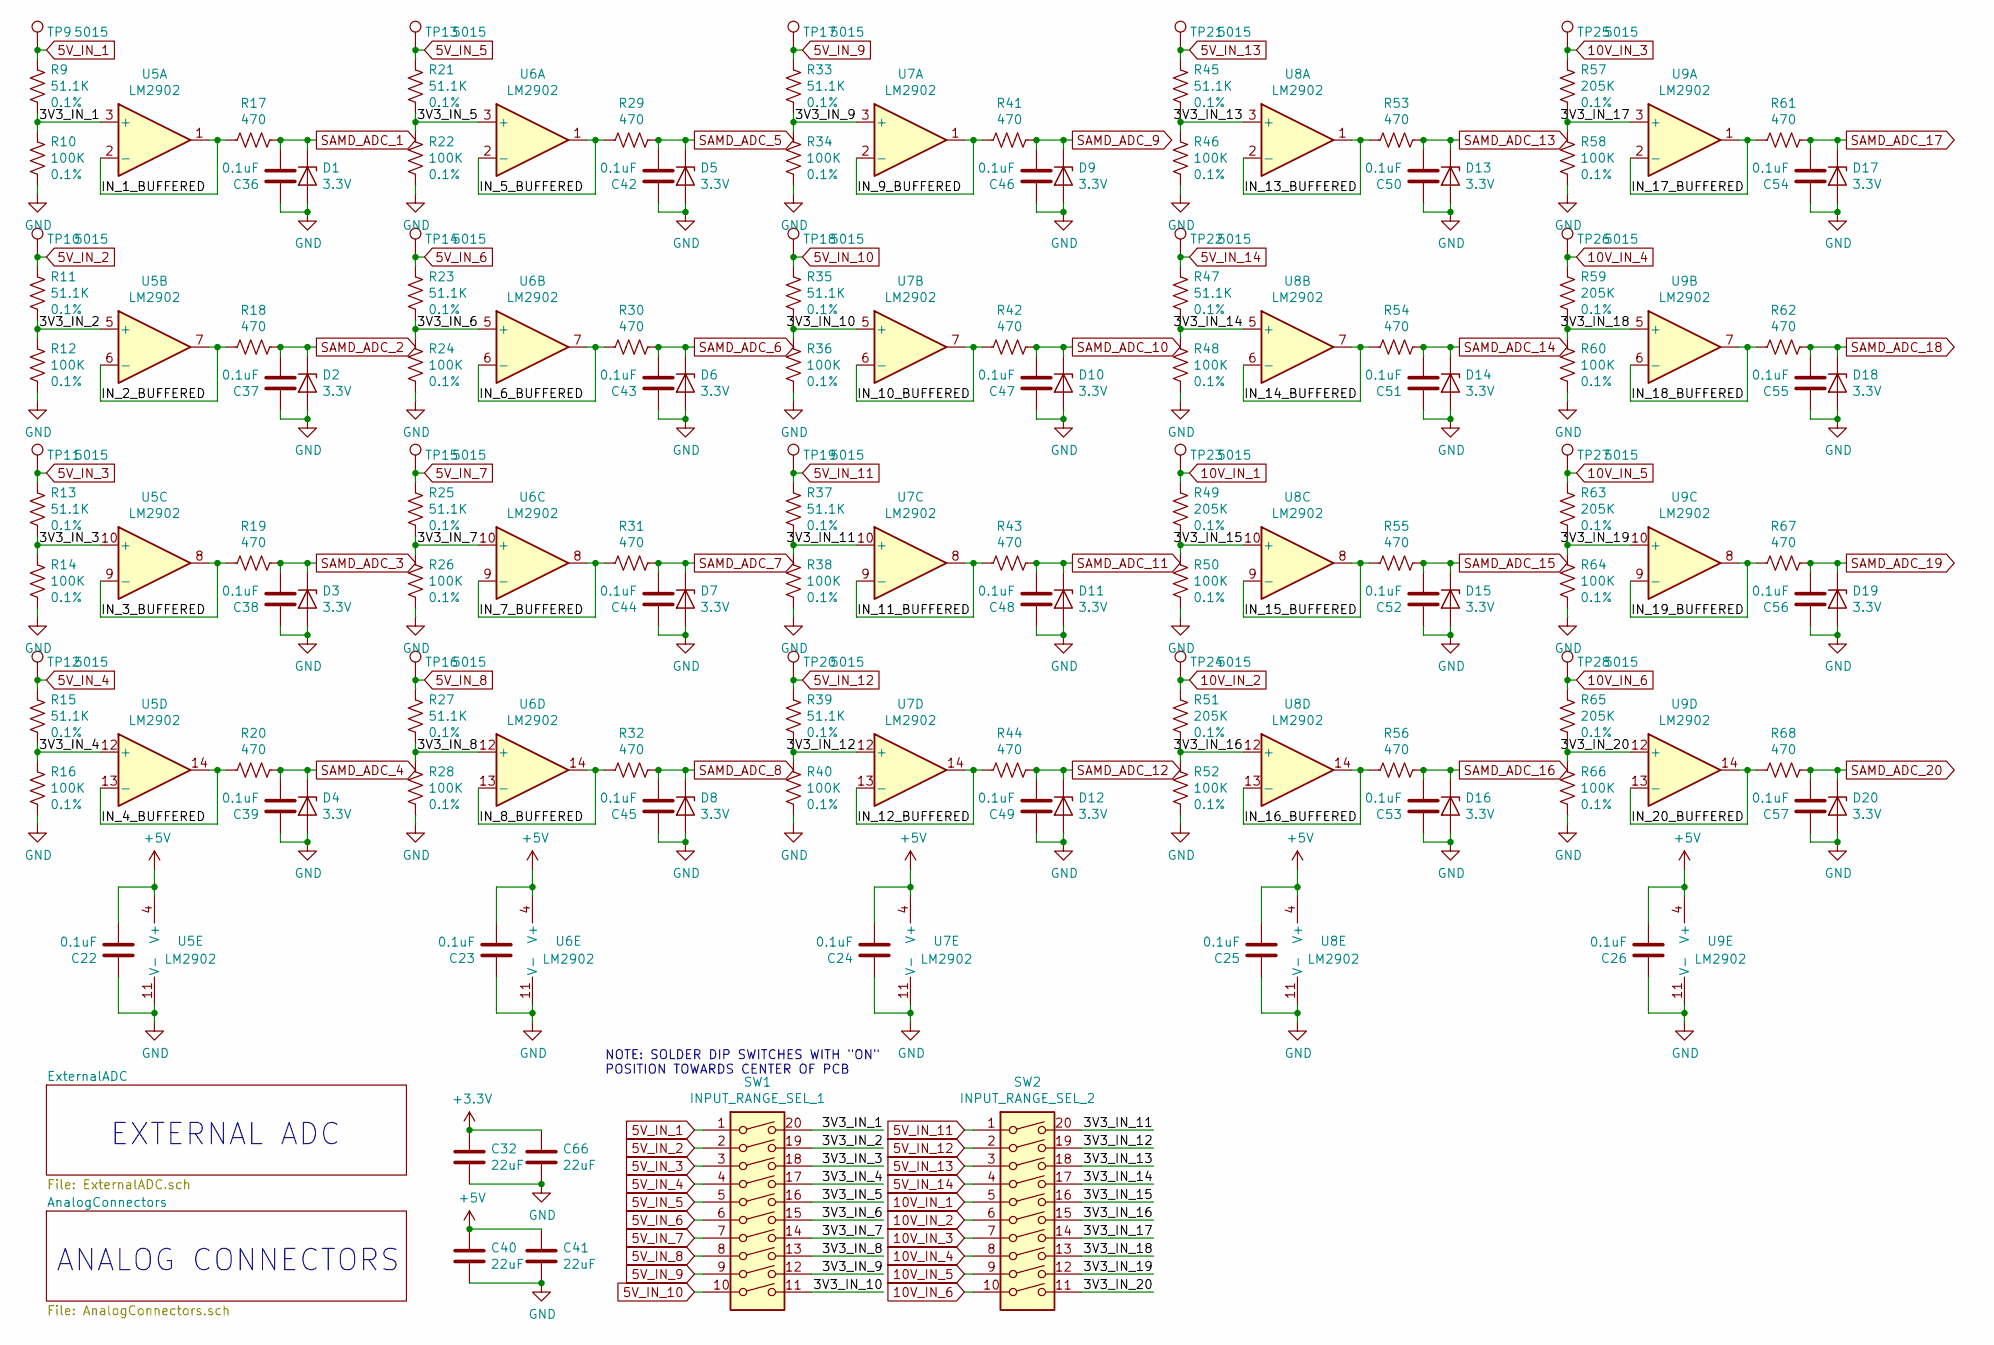
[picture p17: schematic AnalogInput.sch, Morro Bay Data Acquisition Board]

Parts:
C22, C23, C24, C25, C26, C36, C37, C38, C39, C42, C43, C44, C45, C46, C47, C48, C49, C50, C51, C52, C53, C54, C55, C56, C57: 0.1uF; C_0603_1608Metric_Pad1.05x0.95mm_HandSolder; Part Number CC0603KRX7R8BB104
C32, C40, C41, C66: 22uF; C_0805_2012Metric_Pad1.15x1.40mm_HandSolder; Part Number CL21A226MAQNNNE
D1, D2, D3, D4, D5, D6, D7, D8, D9, D10, D11, D12, D13, D14, D15, D16, D17, D18, D19, D20: 3.3V; D_SOD-323_HandSoldering; Part Number MM3Z3V3ST1G
R9, R11, R13, R15, R21, R23, R25, R27, R33, R35, R37, R39, R45, R47: 51.1K; R_0603_1608Metric_Pad1.05x0.95mm_HandSolder; Tolerance 0.1%; Part Number ERJ-PB3B5112V
R10, R12, R14, R16, R22, R24, R26, R28, R34, R36, R38, R40, R46, R48, R50, R52, R58, R60, R64, R66: 100K; R_0603_1608Metric_Pad1.05x0.95mm_HandSolder; Tolerance 0.1%; Part Number ERJ-PB3B1003V
R17, R18, R19, R20, R29, R30, R31, R32, R41, R42, R43, R44, R53, R54, R55, R56, R61, R62, R67, R68: 470; R_0603_1608Metric_Pad1.05x0.95mm_HandSolder; Part Number RMCF0603FT470R
R49, R51, R57, R59, R63, R65: 205K; R_0603_1608Metric_Pad1.05x0.95mm_HandSolder; Tolerance 0.1%; Part Number ERA-3AEB2053V
SW1: INPUT_RANGE_SEL_1; SW_DIP_SPSTx10_Slide_6.7x26.96mm_W8.61mm_P2.54mm_LowProfile; Part Number DS04-254-2-10BK-SMT
SW2: INPUT_RANGE_SEL_2; SW_DIP_SPSTx10_Slide_6.7x26.96mm_W8.61mm_P2.54mm_LowProfile; Part Number DS04-254-2-10BK-SMT
TP9, TP10, TP11, TP12, TP13, TP14, TP15, TP16, TP17, TP18, TP19, TP20, TP21, TP22, TP23, TP24, TP25, TP26, TP27, TP28: 5015; TestPoint_Keystone_5015_Micro-Minature; Part Number 5015
U5: LM2902; SOIC-14_3.9x8.7mm_P1.27mm; Part Number LM2902LVIDR
U6, U7, U8, U9: LM2902; SOIC-14_3.9x8.7mm_P1.27mm

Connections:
5V_IN_1: R9.1, SW1.1, TP9.1; also elsewhere on the board
5V_IN_2: R11.1, SW1.2, TP10.1; also elsewhere on the board
5V_IN_3: R13.1, SW1.3, TP11.1; also elsewhere on the board
5V_IN_4: R15.1, SW1.4, TP12.1; also elsewhere on the board
5V_IN_5: R21.1, SW1.5, TP13.1; also elsewhere on the board
5V_IN_6: R23.1, SW1.6, TP14.1; also elsewhere on the board
5V_IN_7: R25.1, SW1.7, TP15.1; also elsewhere on the board
5V_IN_8: R27.1, SW1.8, TP16.1; also elsewhere on the board
5V_IN_9: R33.1, SW1.9, TP17.1; also elsewhere on the board
5V_IN_10: R35.1, SW1.10, TP18.1; also elsewhere on the board
5V_IN_11: R37.1, SW2.1, TP19.1; also elsewhere on the board
5V_IN_12: R39.1, SW2.2, TP20.1; also elsewhere on the board
5V_IN_13: R45.1, SW2.3, TP21.1; also elsewhere on the board
5V_IN_14: R47.1, SW2.4, TP22.1; also elsewhere on the board
10V_IN_1: R49.1, SW2.5, TP23.1; also elsewhere on the board
10V_IN_2: R51.1, SW2.6, TP24.1; also elsewhere on the board
10V_IN_3: R57.1, SW2.7, TP25.1; also elsewhere on the board
10V_IN_4: R59.1, SW2.8, TP26.1; also elsewhere on the board
10V_IN_5: R63.1, SW2.9, TP27.1; also elsewhere on the board
10V_IN_6: R65.1, SW2.10, TP28.1; also elsewhere on the board
+3V3: C32.1, C66.1; also elsewhere on the board
+5V: C22.2, C23.2, C24.2, C25.2, C26.2, C40.1, C41.1, U5.4 (V+), U6.4 (V+), U7.4 (V+), U8.4 (V+), U9.4 (V+); also elsewhere on the board
/AnalogInput/3V3_IN_1: R9.2, R10.1, SW1.20, U5.3 (+)
/AnalogInput/3V3_IN_2: R11.2, R12.1, SW1.19, U5.5 (+)
/AnalogInput/3V3_IN_3: R13.2, R14.1, SW1.18, U5.10 (+)
/AnalogInput/3V3_IN_4: R15.2, R16.1, SW1.17, U5.12 (+)
/AnalogInput/3V3_IN_5: R21.2, R22.1, SW1.16, U6.3 (+)
/AnalogInput/3V3_IN_6: R23.2, R24.1, SW1.15, U6.5 (+)
/AnalogInput/3V3_IN_7: R25.2, R26.1, SW1.14, U6.10 (+)
/AnalogInput/3V3_IN_8: R27.2, R28.1, SW1.13, U6.12 (+)
/AnalogInput/3V3_IN_9: R33.2, R34.1, SW1.12, U7.3 (+)
/AnalogInput/3V3_IN_10: R35.2, R36.1, SW1.11, U7.5 (+)
/AnalogInput/3V3_IN_11: R37.2, R38.1, SW2.20, U7.10 (+)
/AnalogInput/3V3_IN_12: R39.2, R40.1, SW2.19, U7.12 (+)
/AnalogInput/3V3_IN_13: R45.2, R46.1, SW2.18, U8.3 (+)
/AnalogInput/3V3_IN_14: R47.2, R48.1, SW2.17, U8.5 (+)
/AnalogInput/3V3_IN_15: R49.2, R50.1, SW2.16, U8.10 (+)
/AnalogInput/3V3_IN_16: R51.2, R52.1, SW2.15, U8.12 (+)
/AnalogInput/3V3_IN_17: R57.2, R58.1, SW2.14, U9.3 (+)
/AnalogInput/3V3_IN_18: R59.2, R60.1, SW2.13, U9.5 (+)
/AnalogInput/3V3_IN_19: R63.2, R64.1, SW2.12, U9.10 (+)
/AnalogInput/3V3_IN_20: R65.2, R66.1, SW2.11, U9.12 (+)
/AnalogInput/IN_1_BUFFERED: R17.2, U5.1, U5.2 (-)
/AnalogInput/IN_2_BUFFERED: R18.2, U5.6 (-), U5.7
/AnalogInput/IN_3_BUFFERED: R19.2, U5.8, U5.9 (-)
/AnalogInput/IN_4_BUFFERED: R20.2, U5.13 (-), U5.14
/AnalogInput/IN_5_BUFFERED: R29.2, U6.1, U6.2 (-)
/AnalogInput/IN_6_BUFFERED: R30.2, U6.6 (-), U6.7
/AnalogInput/IN_7_BUFFERED: R31.2, U6.8, U6.9 (-)
/AnalogInput/IN_8_BUFFERED: R32.2, U6.13 (-), U6.14
/AnalogInput/IN_9_BUFFERED: R41.2, U7.1, U7.2 (-)
/AnalogInput/IN_10_BUFFERED: R42.2, U7.6 (-), U7.7
/AnalogInput/IN_11_BUFFERED: R43.2, U7.8, U7.9 (-)
/AnalogInput/IN_12_BUFFERED: R44.2, U7.13 (-), U7.14
/AnalogInput/IN_13_BUFFERED: R53.2, U8.1, U8.2 (-)
/AnalogInput/IN_14_BUFFERED: R54.2, U8.6 (-), U8.7
/AnalogInput/IN_15_BUFFERED: R55.2, U8.8, U8.9 (-)
/AnalogInput/IN_16_BUFFERED: R56.2, U8.13 (-), U8.14
/AnalogInput/IN_17_BUFFERED: R61.2, U9.1, U9.2 (-)
/AnalogInput/IN_18_BUFFERED: R62.2, U9.6 (-), U9.7
/AnalogInput/IN_19_BUFFERED: R67.2, U9.8, U9.9 (-)
/AnalogInput/IN_20_BUFFERED: R68.2, U9.13 (-), U9.14
GND: C22.1, C23.1, C24.1, C25.1, C26.1, C32.2, C36.1, C37.1, C38.1, C39.1, C40.2, C41.2, C42.1, C43.1, C44.1, C45.1, C46.1, C47.1, C48.1, C49.1, C50.1, C51.1, C52.1, C53.1, C54.1, C55.1, C56.1, C57.1, C66.2, D1.2 (A), D2.2 (A), D3.2 (A), D4.2 (A), D5.2 (A), D6.2 (A), D7.2 (A), D8.2 (A), D9.2 (A), D10.2 (A), D11.2 (A), D12.2 (A), D13.2 (A), D14.2 (A), D15.2 (A), D16.2 (A), D17.2 (A), D18.2 (A), D19.2 (A), D20.2 (A), R10.2, R12.2, R14.2, R16.2, R22.2, R24.2, R26.2, R28.2, R34.2, R36.2, R38.2, R40.2, R46.2, R48.2, R50.2, R52.2, R58.2, R60.2, R64.2, R66.2, U5.11 (V-), U6.11 (V-), U7.11 (V-), U8.11 (V-), U9.11 (V-); also elsewhere on the board
SAMD_ADC_1: C36.2, D1.1 (K), R17.1; also elsewhere on the board
SAMD_ADC_2: C37.2, D2.1 (K), R18.1; also elsewhere on the board
SAMD_ADC_3: C38.2, D3.1 (K), R19.1; also elsewhere on the board
SAMD_ADC_4: C39.2, D4.1 (K), R20.1; also elsewhere on the board
SAMD_ADC_5: C42.2, D5.1 (K), R29.1; also elsewhere on the board
SAMD_ADC_6: C43.2, D6.1 (K), R30.1; also elsewhere on the board
SAMD_ADC_7: C44.2, D7.1 (K), R31.1; also elsewhere on the board
SAMD_ADC_8: C45.2, D8.1 (K), R32.1; also elsewhere on the board
SAMD_ADC_9: C46.2, D9.1 (K), R41.1; also elsewhere on the board
SAMD_ADC_10: C47.2, D10.1 (K), R42.1; also elsewhere on the board
SAMD_ADC_11: C48.2, D11.1 (K), R43.1; also elsewhere on the board
SAMD_ADC_12: C49.2, D12.1 (K), R44.1; also elsewhere on the board
SAMD_ADC_13: C50.2, D13.1 (K), R53.1; also elsewhere on the board
SAMD_ADC_14: C51.2, D14.1 (K), R54.1; also elsewhere on the board
SAMD_ADC_15: C52.2, D15.1 (K), R55.1; also elsewhere on the board
SAMD_ADC_16: C53.2, D16.1 (K), R56.1; also elsewhere on the board
SAMD_ADC_17: C54.2, D17.1 (K), R61.1; also elsewhere on the board
SAMD_ADC_18: C55.2, D18.1 (K), R62.1; also elsewhere on the board
SAMD_ADC_19: C56.2, D19.1 (K), R67.1; also elsewhere on the board
SAMD_ADC_20: C57.2, D20.1 (K), R68.1; also elsewhere on the board

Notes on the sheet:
ANALOG CONNECTORS
EXTERNAL ADC
NOTE: SOLDER DIP SWITCHES WITH "ON" POSITION TOWARDS CENTER OF PCB

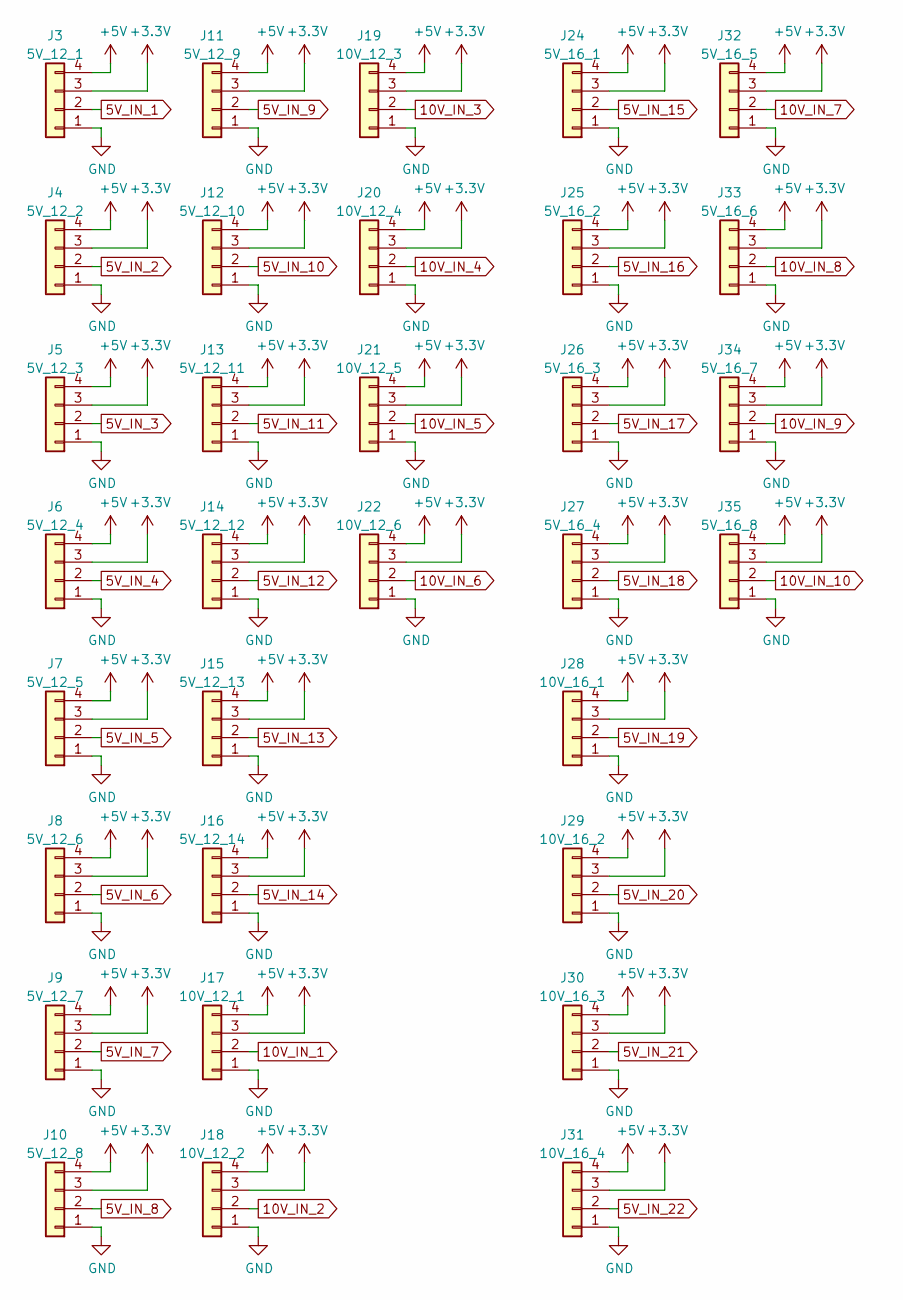
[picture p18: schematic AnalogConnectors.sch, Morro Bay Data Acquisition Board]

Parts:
J3: 5V_12_1; Connector_Molex_SL_4POS_0705510038; Part Number 0705510038
J4: 5V_12_2; Connector_Molex_SL_4POS_0705510038; Part Number 0705510038
J5: 5V_12_3; Connector_Molex_SL_4POS_0705510038; Part Number 0705510038
J6: 5V_12_4; Connector_Molex_SL_4POS_0705510038; Part Number 0705510038
J7: 5V_12_5; Connector_Molex_SL_4POS_0705510038; Part Number 0705510038
J8: 5V_12_6; Connector_Molex_SL_4POS_0705510038; Part Number 0705510038
J9: 5V_12_7; Connector_Molex_SL_4POS_0705510038; Part Number 0705510038
J10: 5V_12_8; Connector_Molex_SL_4POS_0705510038; Part Number 0705510038
J11: 5V_12_9; Connector_Molex_SL_4POS_0705510038; Part Number 0705510038
J12: 5V_12_10; Connector_Molex_SL_4POS_0705510038; Part Number 0705510038
J13: 5V_12_11; Connector_Molex_SL_4POS_0705510038; Part Number 0705510038
J14: 5V_12_12; Connector_Molex_SL_4POS_0705510038; Part Number 0705510038
J15: 5V_12_13; Connector_Molex_SL_4POS_0705510038; Part Number 0705510038
J16: 5V_12_14; Connector_Molex_SL_4POS_0705510038; Part Number 0705510038
J17: 10V_12_1; Connector_Molex_SL_4POS_0705510038; Part Number 0705510038
J18: 10V_12_2; Connector_Molex_SL_4POS_0705510038; Part Number 0705510038
J19: 10V_12_3; Connector_Molex_SL_4POS_0705510038; Part Number 0705510038
J20: 10V_12_4; Connector_Molex_SL_4POS_0705510038; Part Number 0705510038
J21: 10V_12_5; Connector_Molex_SL_4POS_0705510038; Part Number 0705510038
J22: 10V_12_6; Connector_Molex_SL_4POS_0705510038; Part Number 0705510038
J24: 5V_16_1; Connector_Molex_SL_4POS_0705510038; Part Number 0705510038
J25: 5V_16_2; Connector_Molex_SL_4POS_0705510038; Part Number 0705510038
J26: 5V_16_3; Connector_Molex_SL_4POS_0705510038; Part Number 0705510038
J27: 5V_16_4; Connector_Molex_SL_4POS_0705510038; Part Number 0705510038
J28: 10V_16_1; Connector_Molex_SL_4POS_0705510038; Part Number 0705510038
J29: 10V_16_2; Connector_Molex_SL_4POS_0705510038; Part Number 0705510038
J30: 10V_16_3; Connector_Molex_SL_4POS_0705510038; Part Number 0705510038
J31: 10V_16_4; Connector_Molex_SL_4POS_0705510038; Part Number 0705510038
J32: 5V_16_5; Connector_Molex_SL_4POS_0705510038; Part Number 0705510038
J33: 5V_16_6; Connector_Molex_SL_4POS_0705510038; Part Number 0705510038
J34: 5V_16_7; Connector_Molex_SL_4POS_0705510038; Part Number 0705510038
J35: 5V_16_8; Connector_Molex_SL_4POS_0705510038; Part Number 0705510038

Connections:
5V_IN_1: J3.2; also elsewhere on the board
5V_IN_2: J4.2; also elsewhere on the board
5V_IN_3: J5.2; also elsewhere on the board
5V_IN_4: J6.2; also elsewhere on the board
5V_IN_5: J7.2; also elsewhere on the board
5V_IN_6: J8.2; also elsewhere on the board
5V_IN_7: J9.2; also elsewhere on the board
5V_IN_8: J10.2; also elsewhere on the board
5V_IN_9: J11.2; also elsewhere on the board
5V_IN_10: J12.2; also elsewhere on the board
5V_IN_11: J13.2; also elsewhere on the board
5V_IN_12: J14.2; also elsewhere on the board
5V_IN_13: J15.2; also elsewhere on the board
5V_IN_14: J16.2; also elsewhere on the board
5V_IN_15: J24.2; also elsewhere on the board
5V_IN_16: J25.2; also elsewhere on the board
5V_IN_17: J26.2; also elsewhere on the board
5V_IN_18: J27.2; also elsewhere on the board
5V_IN_19: J28.2; also elsewhere on the board
5V_IN_20: J29.2; also elsewhere on the board
5V_IN_21: J30.2; also elsewhere on the board
5V_IN_22: J31.2; also elsewhere on the board
10V_IN_1: J17.2; also elsewhere on the board
10V_IN_2: J18.2; also elsewhere on the board
10V_IN_3: J19.2; also elsewhere on the board
10V_IN_4: J20.2; also elsewhere on the board
10V_IN_5: J21.2; also elsewhere on the board
10V_IN_6: J22.2; also elsewhere on the board
10V_IN_7: J32.2; also elsewhere on the board
10V_IN_8: J33.2; also elsewhere on the board
10V_IN_9: J34.2; also elsewhere on the board
10V_IN_10: J35.2; also elsewhere on the board
+3V3: J3.3, J4.3, J5.3, J6.3, J7.3, J8.3, J9.3, J10.3, J11.3, J12.3, J13.3, J14.3, J15.3, J16.3, J17.3, J18.3, J19.3, J20.3, J21.3, J22.3, J24.3, J25.3, J26.3, J27.3, J28.3, J29.3, J30.3, J31.3, J32.3, J33.3, J34.3, J35.3; also elsewhere on the board
+5V: J3.4, J4.4, J5.4, J6.4, J7.4, J8.4, J9.4, J10.4, J11.4, J12.4, J13.4, J14.4, J15.4, J16.4, J17.4, J18.4, J19.4, J20.4, J21.4, J22.4, J24.4, J25.4, J26.4, J27.4, J28.4, J29.4, J30.4, J31.4, J32.4, J33.4, J34.4, J35.4; also elsewhere on the board
GND: J3.1, J4.1, J5.1, J6.1, J7.1, J8.1, J9.1, J10.1, J11.1, J12.1, J13.1, J14.1, J15.1, J16.1, J17.1, J18.1, J19.1, J20.1, J21.1, J22.1, J24.1, J25.1, J26.1, J27.1, J28.1, J29.1, J30.1, J31.1, J32.1, J33.1, J34.1, J35.1; also elsewhere on the board

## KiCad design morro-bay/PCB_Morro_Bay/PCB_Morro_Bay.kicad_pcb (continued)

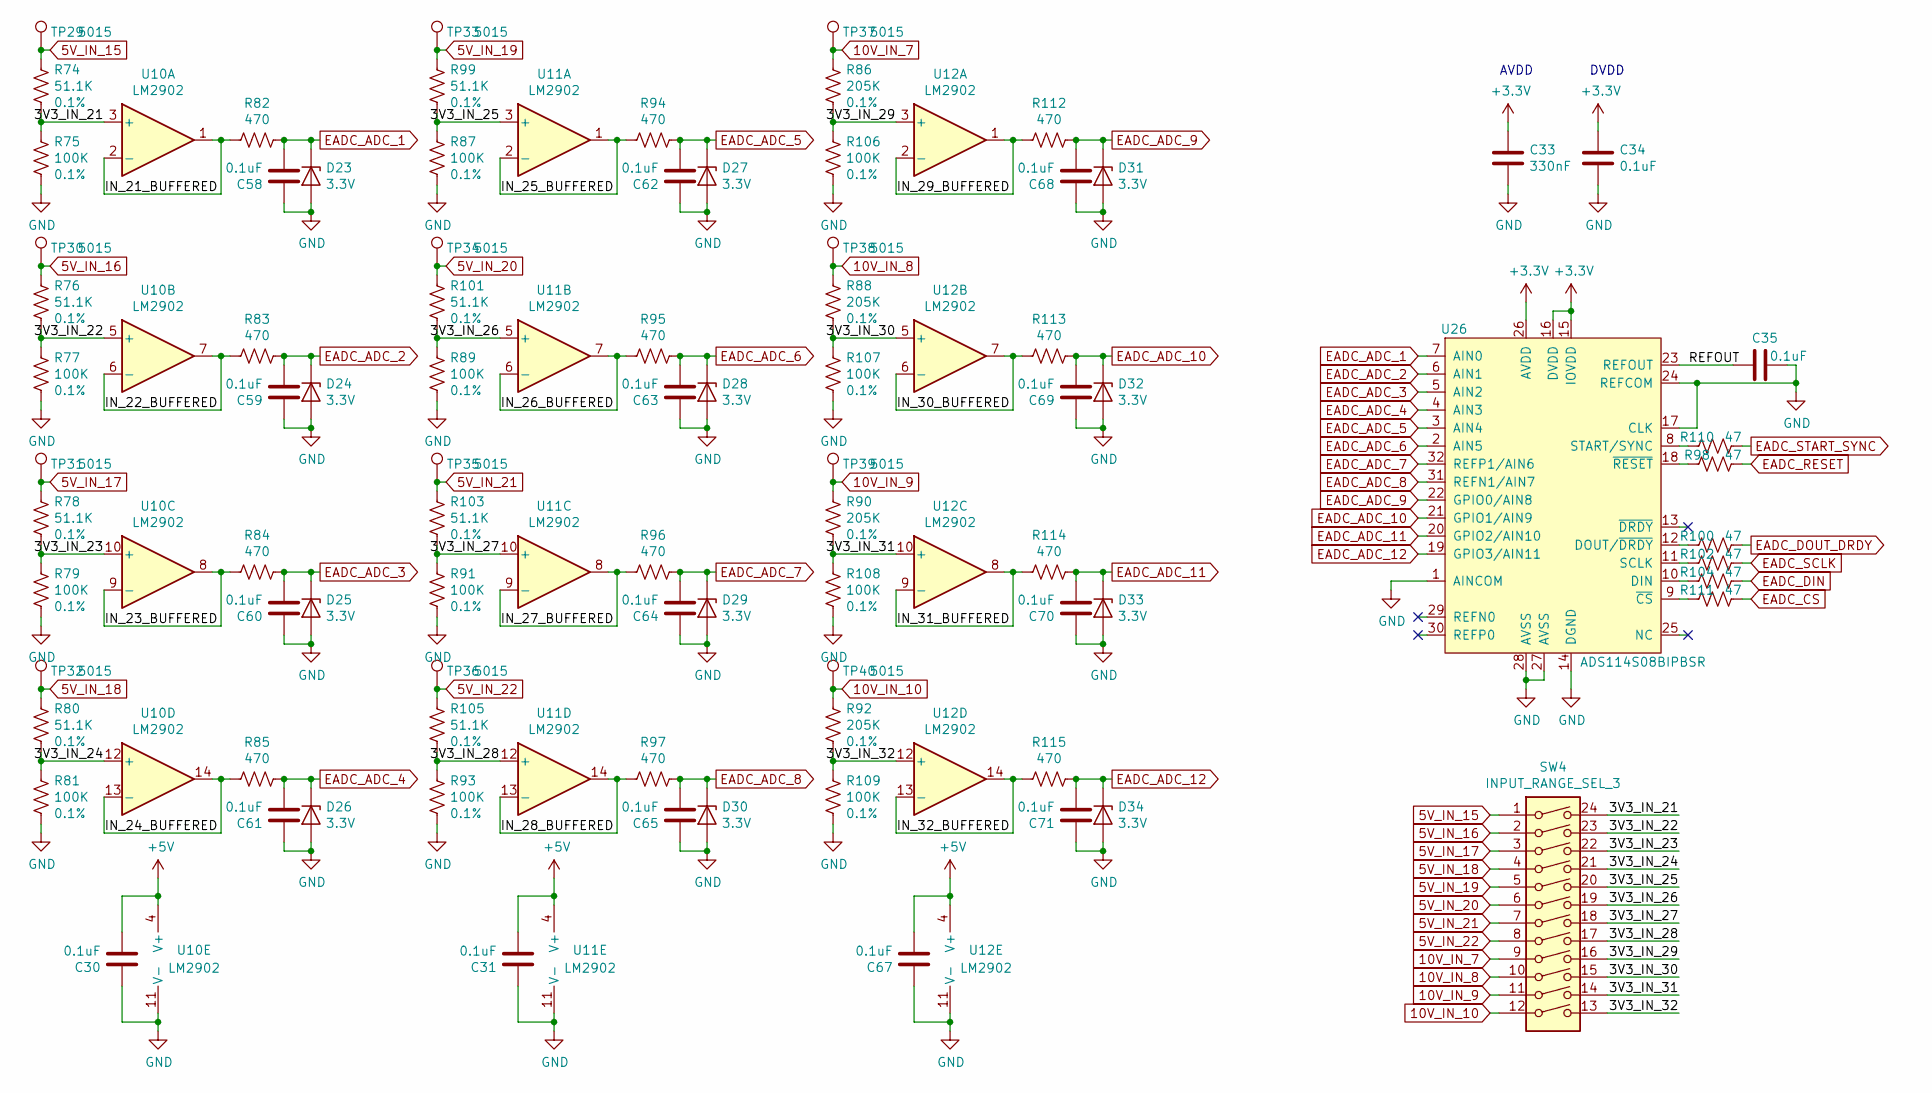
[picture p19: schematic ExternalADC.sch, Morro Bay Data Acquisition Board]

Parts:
C30, C31, C34, C35, C58, C59, C60, C61, C62, C63, C64, C65, C67, C68, C69, C70, C71: 0.1uF; C_0603_1608Metric_Pad1.05x0.95mm_HandSolder; Part Number CC0603KRX7R8BB104
C33: 330nF; C_0603_1608Metric_Pad1.05x0.95mm_HandSolder; Part Number C0603C331J5GACTU
D23, D24, D25, D26, D27, D28, D29, D30, D31, D32, D33, D34: 3.3V; D_SOD-323_HandSoldering; Part Number MM3Z3V3ST1G
R74, R76, R78, R80, R99, R101, R103, R105: 51.1K; R_0603_1608Metric_Pad1.05x0.95mm_HandSolder; Tolerance 0.1%; Part Number ERJ-PB3B5112V
R75, R77, R79, R81, R87, R89, R91, R93, R106, R107, R108, R109: 100K; R_0603_1608Metric_Pad1.05x0.95mm_HandSolder; Tolerance 0.1%; Part Number ERJ-PB3B1003V
R82, R83, R84, R85, R94, R95, R96, R97, R112, R113, R114, R115: 470; R_0603_1608Metric_Pad1.05x0.95mm_HandSolder; Part Number RMCF0603FT470R
R86, R88, R90, R92: 205K; R_0603_1608Metric_Pad1.05x0.95mm_HandSolder; Tolerance 0.1%; Part Number ERA-3AEB2053V
R98, R100, R102, R104, R110, R111: 47; R_0603_1608Metric_Pad1.05x0.95mm_HandSolder; Part Number RMCF0603FT47R0
SW4: INPUT_RANGE_SEL_3; SW_DIP_SPSTx12_Slide_6.7x32.04mm_W8.61mm_P2.54mm_LowProfile; Part Number DS04-254-2-12BK-SMT
TP29, TP30, TP31, TP32, TP33, TP34, TP35, TP36, TP37, TP38, TP39, TP40: 5015; TestPoint_Keystone_5015_Micro-Minature; Part Number 5015
U10, U11, U12: LM2902; SOIC-14_3.9x8.7mm_P1.27mm
U26: ADS114S08BIPBSR; LQFP-32_5x5mm_P0.5mm; Part Number ADS114S08BIPBSR

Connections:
5V_IN_15: R74.1, SW4.1, TP29.1; also elsewhere on the board
5V_IN_16: R76.1, SW4.2, TP30.1; also elsewhere on the board
5V_IN_17: R78.1, SW4.3, TP31.1; also elsewhere on the board
5V_IN_18: R80.1, SW4.4, TP32.1; also elsewhere on the board
5V_IN_19: R99.1, SW4.5, TP33.1; also elsewhere on the board
5V_IN_20: R101.1, SW4.6, TP34.1; also elsewhere on the board
5V_IN_21: R103.1, SW4.7, TP35.1; also elsewhere on the board
5V_IN_22: R105.1, SW4.8, TP36.1; also elsewhere on the board
10V_IN_7: R86.1, SW4.9, TP37.1; also elsewhere on the board
10V_IN_8: R88.1, SW4.10, TP38.1; also elsewhere on the board
10V_IN_9: R90.1, SW4.11, TP39.1; also elsewhere on the board
10V_IN_10: R92.1, SW4.12, TP40.1; also elsewhere on the board
+3V3: C33.1, C34.1, U26.15 (IOVDD), U26.16 (DVDD), U26.26 (AVDD); also elsewhere on the board
+5V: C30.2, C31.2, C67.2, U10.4 (V+), U11.4 (V+), U12.4 (V+); also elsewhere on the board
/AnalogInput/ExternalADC/3V3_IN_21: R74.2, R75.1, SW4.24, U10.3 (+)
/AnalogInput/ExternalADC/3V3_IN_22: R76.2, R77.1, SW4.23, U10.5 (+)
/AnalogInput/ExternalADC/3V3_IN_23: R78.2, R79.1, SW4.22, U10.10 (+)
/AnalogInput/ExternalADC/3V3_IN_24: R80.2, R81.1, SW4.21, U10.12 (+)
/AnalogInput/ExternalADC/3V3_IN_25: R87.1, R99.2, SW4.20, U11.3 (+)
/AnalogInput/ExternalADC/3V3_IN_26: R89.1, R101.2, SW4.19, U11.5 (+)
/AnalogInput/ExternalADC/3V3_IN_27: R91.1, R103.2, SW4.18, U11.10 (+)
/AnalogInput/ExternalADC/3V3_IN_28: R93.1, R105.2, SW4.17, U11.12 (+)
/AnalogInput/ExternalADC/3V3_IN_29: R86.2, R106.1, SW4.16, U12.3 (+)
/AnalogInput/ExternalADC/3V3_IN_30: R88.2, R107.1, SW4.15, U12.5 (+)
/AnalogInput/ExternalADC/3V3_IN_31: R90.2, R108.1, SW4.14, U12.10 (+)
/AnalogInput/ExternalADC/3V3_IN_32: R92.2, R109.1, SW4.13, U12.12 (+)
/AnalogInput/ExternalADC/IN_21_BUFFERED: R82.2, U10.1, U10.2 (-)
/AnalogInput/ExternalADC/IN_22_BUFFERED: R83.2, U10.6 (-), U10.7
/AnalogInput/ExternalADC/IN_23_BUFFERED: R84.2, U10.8, U10.9 (-)
/AnalogInput/ExternalADC/IN_24_BUFFERED: R85.2, U10.13 (-), U10.14
/AnalogInput/ExternalADC/IN_25_BUFFERED: R94.2, U11.1, U11.2 (-)
/AnalogInput/ExternalADC/IN_26_BUFFERED: R95.2, U11.6 (-), U11.7
/AnalogInput/ExternalADC/IN_27_BUFFERED: R96.2, U11.8, U11.9 (-)
/AnalogInput/ExternalADC/IN_28_BUFFERED: R97.2, U11.13 (-), U11.14
/AnalogInput/ExternalADC/IN_29_BUFFERED: R112.2, U12.1, U12.2 (-)
/AnalogInput/ExternalADC/IN_30_BUFFERED: R113.2, U12.6 (-), U12.7
/AnalogInput/ExternalADC/IN_31_BUFFERED: R114.2, U12.8, U12.9 (-)
/AnalogInput/ExternalADC/IN_32_BUFFERED: R115.2, U12.13 (-), U12.14
/AnalogInput/ExternalADC/REFOUT: C35.2, U26.23 (REFOUT)
EADC_ADC_1: C58.2, D23.1 (K), R82.1, U26.7 (AIN0)
EADC_ADC_2: C59.2, D24.1 (K), R83.1, U26.6 (AIN1)
EADC_ADC_3: C60.2, D25.1 (K), R84.1, U26.5 (AIN2)
EADC_ADC_4: C61.2, D26.1 (K), R85.1, U26.4 (AIN3)
EADC_ADC_5: C62.2, D27.1 (K), R94.1, U26.3 (AIN4)
EADC_ADC_6: C63.2, D28.1 (K), R95.1, U26.2 (AIN5)
EADC_ADC_7: C64.2, D29.1 (K), R96.1, U26.32 (REFP1/AIN6)
EADC_ADC_8: C65.2, D30.1 (K), R97.1, U26.31 (REFN1/AIN7)
EADC_ADC_9: C68.2, D31.1 (K), R112.1, U26.22 (GPIO0/AIN8)
EADC_ADC_10: C69.2, D32.1 (K), R113.1, U26.21 (GPIO1/AIN9)
EADC_ADC_11: C70.2, D33.1 (K), R114.1, U26.20 (GPIO2/AIN10)
EADC_ADC_12: C71.2, D34.1 (K), R115.1, U26.19 (GPIO3/AIN11)
EADC_CS: R111.2; also elsewhere on the board
EADC_DIN: R104.2; also elsewhere on the board
EADC_DOUT_DRDY: R100.2; also elsewhere on the board
EADC_RESET: R98.2; also elsewhere on the board
EADC_SCLK: R102.2; also elsewhere on the board
EADC_START_SYNC: R110.2; also elsewhere on the board
GND: C30.1, C31.1, C33.2, C34.2, C35.1, C58.1, C59.1, C60.1, C61.1, C62.1, C63.1, C64.1, C65.1, C67.1, C68.1, C69.1, C70.1, C71.1, D23.2 (A), D24.2 (A), D25.2 (A), D26.2 (A), D27.2 (A), D28.2 (A), D29.2 (A), D30.2 (A), D31.2 (A), D32.2 (A), D33.2 (A), D34.2 (A), R75.2, R77.2, R79.2, R81.2, R87.2, R89.2, R91.2, R93.2, R106.2, R107.2, R108.2, R109.2, U10.11 (V-), U11.11 (V-), U12.11 (V-), U26.1 (AINCOM), U26.14 (DGND), U26.17 (CLK), U26.24 (REFCOM), U26.27 (AVSS), U26.28 (AVSS); also elsewhere on the board
unnamed: R98.1, U26.18 (~RESET~)
unnamed: R100.1, U26.12 (DOUT/~DRDY~)
unnamed: R102.1, U26.11 (SCLK)
unnamed: R104.1, U26.10 (DIN)
unnamed: R110.1, U26.8 (START/SYNC)
unnamed: R111.1, U26.9 (~CS~)

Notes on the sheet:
AVDD
DVDD

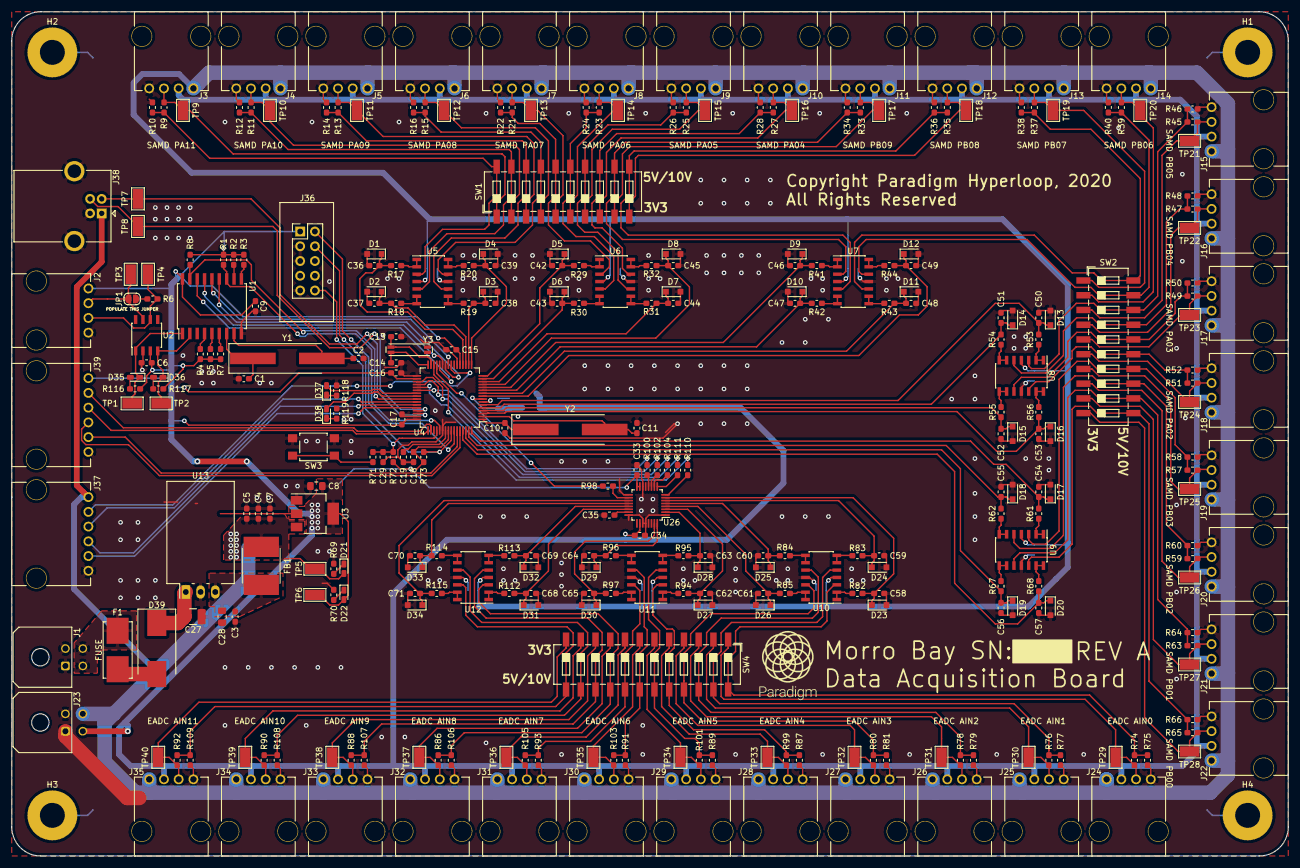
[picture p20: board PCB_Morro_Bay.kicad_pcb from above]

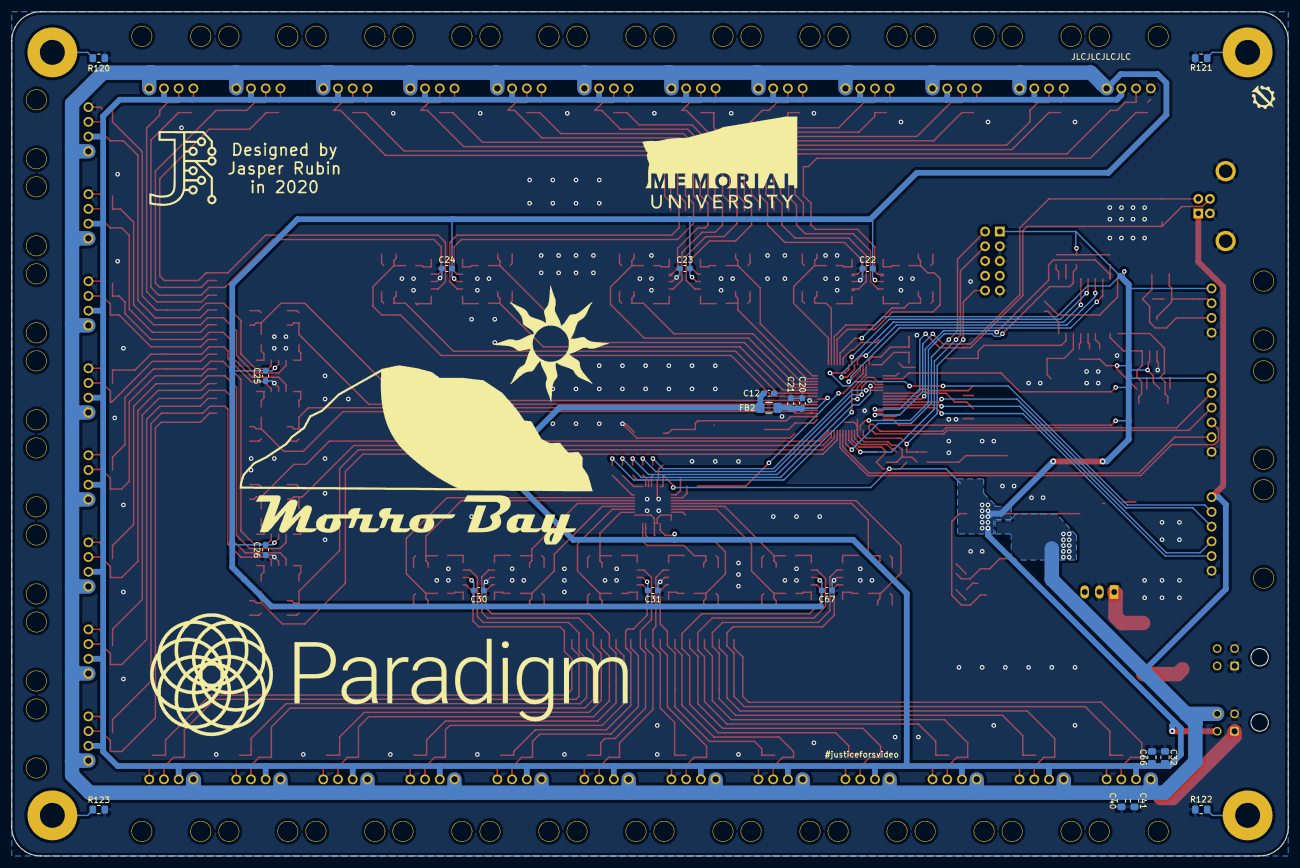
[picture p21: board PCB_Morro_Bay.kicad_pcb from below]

Board: 2 copper layers, 220.0 x 145.5 mm, 341 parts (20 on the bottom side), 198 nets.

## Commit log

2020-02-04 Add Morro Bay project
    [PCB_Morro_Bay.kicad_pcb, PCB_Morro_Bay.sch]
2020-02-04 Add Kicad template to master
2020-02-04 Add CAN controller, USB connector
2020-02-06 Add SAMD21, 3.3V regulator
    [PCB_Morro_Bay.sch]
2020-02-06 Add CAN transceiver
    [PCB_Morro_Bay.sch]
2020-02-06 Change CAN transceiver to 3.3V
    [PCB_Morro_Bay.sch]
2020-02-07 Add decoupling and analog power filtering for SAMD
    [PCB_Morro_Bay.sch]
2020-02-08 Add crystals
    [PCB_Morro_Bay.sch]
2020-02-10 Add analog resistor dividers
    [AnalogInput.sch, PCB_Morro_Bay.sch]
2020-02-11 Work on analog inputs
    [AnalogInput.sch, PCB_Morro_Bay.sch]
2020-02-16 Work on analog inputs and pin naming
    [AnalogInput.sch, PCB_Morro_Bay.sch]
2020-02-17 Add input connectors, DIP switches
    [AnalogConnectors.sch, AnalogInput.sch, Connectors.sch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]
2020-02-22 Switch to DC-DC reg
    [AnalogInput.sch, PCB_Morro_Bay.sch]
2020-02-24 Add external ADC
    [AnalogConnectors.sch, AnalogInput.sch, ExternalADC.sch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]
2020-02-26 WindTunnel_StrainGauge_Schematic
    The strain gauges are in a Wheatstone bridge configuration. The two outputs of the Wheatstone bridge are connected to an AD260 In Amp. The output of this amplifier is then connected to an arduino .
    [Wind_Tunnel_Electronics_Schematic.sch]
2020-02-26 Added strain gauge schematic from Rohan
    [Wind_Tunnel_Electronics_Schematic.sch]
2020-02-26 Move strain gauge to morro bay branch
    [Wind_Tunnel_Electronics_Schematic.sch]
2020-02-29 External ADC, SPI
    [AnalogConnectors.sch, ExternalADC.sch, PCB_Morro_Bay.sch]
2020-02-29 Ready for initial sch review
    [AnalogInput.sch, ExternalADC.sch, PCB_Morro_Bay.sch]
2020-03-01 Add files via upload
    4 strain gauges in full bridge configuration, the differential output of the bridge is connected to an In Amp for amplification.
    [Strain_Gauge_Full_Bridge_Schematic.sch]
2020-03-03 Create Strain-Gauge-Schematic
2020-03-03 Add files via upload
    Within the testing apparatus, there are two rods used for mounting the object to be tested. On each of these rods, there is one set of strain gauges in full bridge configuration. Full bridge configuration is used as it has maximum sensitivity and is temperature compensated. The differential output of the bridge is connected to an instrumentation amplifier for amplification and noise reduction. Note that the output of this entire circuit yields an analog input between 0-5 V.
    [Strain_Gauge_Full_Bridge_Schematic.sch]
2020-03-03 Create Pressure_Sensor
2020-03-03 Add files via upload
    Each pressure sensor has a supply voltage of 5V, output voltage range from 0-5V, the operating range of the current pressure sensor is from 15 -115 KPA, and the sensors are temperature compensated. N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
    [Pressure_Sensor_Schematic.sch]
2020-03-17 Work on BOM
    [AnalogConnectors.sch, AnalogInput.sch, ExternalADC.sch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]
2020-03-19 More BOM
    And if that don't work, use more gun.
    [AnalogConnectors.sch, AnalogInput.sch, ExternalADC.sch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]
2020-03-19 More bom
    [PCB_Morro_Bay.sch]
2020-03-22 Even more BOM and footprints
    [AnalogInput.sch, ExternalADC.sch, PCB_Morro_Bay.sch]
2020-03-22 BOM BOM BOM BOM baBOM BOM baBOM...
    (Imperial march)
    [AnalogConnectors.sch, AnalogInput.sch, BOM_Mar_22.xlsx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]
2020-03-29 Start layout, finish BOM
    [AnalogConnectors.sch, AnalogInput.sch, ExternalADC.sch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]
2020-03-31 Fix values of C7 and C8
    [AnalogConnectors.sch, AnalogInput.sch, BOM_Mar_31.xlsx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]
2020-04-02 Much layout
    [PCB_Morro_Bay.kicad_pcb]
2020-04-05 Start routing
    [AnalogInput.sch, PCB_Morro_Bay.kicad_pcb]
2020-04-12 Routing and layout work
    [PCB_Morro_Bay.kicad_pcb, PCB_Morro_Bay.sch]
2020-04-17 Routed some things
    [PCB_Morro_Bay.kicad_pcb]
2020-04-20 More routing
    [AnalogConnectors.sch, ExternalADC.sch, PCB_Morro_Bay.kicad_pcb]
2020-04-28 Add CAN termination marking
    [PCB_Morro_Bay.kicad_pcb]
2020-05-01 Update from Fronk's review
    [PCB_Morro_Bay.kicad_pcb]
2020-05-02 Add direction silkscreen for DIP switches
    [AnalogInput.sch, PCB_Morro_Bay.kicad_pcb]
2020-05-02 Add 3D models for connectors
    [430450400.stp, 705510005.stp, 705510038.stp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]
2020-05-05 Export Gerbers
    [PCB_Morro_Bay-B_Cu.gbr, PCB_Morro_Bay-B_Mask.gbr, PCB_Morro_Bay-B_Paste.gbr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]
2020-05-05 Add missing part values
    [BOM_May_05.xlsx, PCB_Morro_Bay.kicad_pcb, PCB_Morro_Bay.sch]
2020-05-06 Create PressureSensorV1
2020-05-06 Fix silk and export new gerbers
    [BOM_May_05.xlsx, Bom_Digi.xlsx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]
2020-06-11 Export final gerbers for MB
    [AnalogInput.sch, Bom_Digi.xlsx, ExternalADC.sch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]

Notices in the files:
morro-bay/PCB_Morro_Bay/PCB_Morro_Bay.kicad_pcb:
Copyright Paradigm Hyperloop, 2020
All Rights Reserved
